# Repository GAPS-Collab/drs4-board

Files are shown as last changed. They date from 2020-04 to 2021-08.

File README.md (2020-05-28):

# Intro
 - altium: contains ECAD project files
 - mfg: contains CAM files (for production ready revisions)
 - peripherals: helpful spreadsheets for address mapping
 - pdf: pdf documents

## Mandatory
Altium does not embed design rules, **they must be imported locally**. When contributing to this project, ensure that you've imported (and are keeping up to date) `altium/rules`

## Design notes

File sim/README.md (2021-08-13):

# SPICE Simulations

Folder containing LTSpice schematics

## Timing calibration LP filter

File: `cheb_7ord.asc`

A high precision (+- 500 ppb) 25 MHz 3V3 LVCMOS (AST3TQ-25.000MHZ-5) TCXO is used for the calibration source. It's make compatible with the DRS4 dynamic range and also shaped using a 7th order Chebyshev LP filter resulting in a roughly 430 mVpp sinewave.

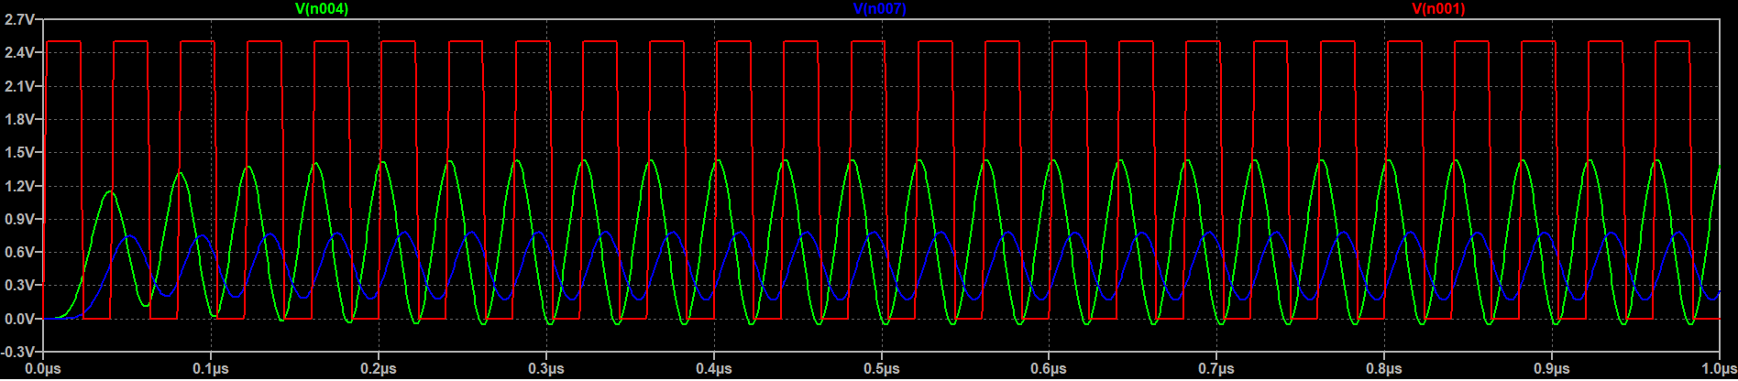
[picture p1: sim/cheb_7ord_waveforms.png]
Example waveform


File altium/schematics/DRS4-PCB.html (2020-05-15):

Altium customize

# Board Information Report

Date: | | 7/10/2019
Time: | | 3:52:31 PM
Elapsed Time: | | 00:00:01
Filename: | | C:\Users\Ismael\Dropbox\GAPS\DRS4_V2\UCLA-DRS4-V2\schematics\DRS4-PCB.PcbDoc
Units: | | mmmils

## Contents

Contents

Board Specification

General

Routing

Routing Information

Layer Information

Layer Information

Drill Pairs

Board Holes

Non-Plated Hole Size

Plated Hole Size

Board Slots

Non-Plated Slot Size

Plated Slot Size

Board Square Holes

Non-Plated Square Hole Size

Plated Square Hole Size

Other

Top Layer Annular Ring Size

Mid Layer Annular Ring Size

Bottom Layer Annular Ring Size

Pad Solder Mask

Pad Paste Mask

Pad Pwr/Gnd Expansion

Pad Relief Conductor Width

Pad Relief Air Gap

Pad Relief Entries

Via Solder Mask

Via Pwr/Gnd Expansion

Track Width

Arc Line Width

Arc Radius

Arc Degrees

Text Height

Text Width

Net Track Width

Net Via Size

## Board Specification

General
Board Size | 313.69mm x 183.14mm
Components on board | 1321

Back to top

## Routing

Routing Information
Routing completion | 80.89%
Connections | 2982
Connections routed | 2412
Connections remaining | 570

Back to top

## Layer Information

Layer | Arcs | Pads | Vias | Tracks | Texts | Fills | Regions | ComponentBodies
Top Layer | 86 | 2519 | 0 | 3016 | 0 | 0 | 257 | 0
Ground Layer 2 | 0 | 0 | 0 | 0 | 0 | 0 | 3 | 0
Signal Layer 3 | 0 | 0 | 0 | 559 | 0 | 0 | 2 | 0
Signal Layer 4 | 1078 | 0 | 0 | 534 | 0 | 0 | 9 | 0
Ground Layer 5 | 0 | 0 | 0 | 0 | 0 | 0 | 0 | 0
Power Layer 6 | 0 | 0 | 0 | 0 | 0 | 0 | 5 | 0
Ground Layer 7 | 0 | 0 | 0 | 0 | 0 | 0 | 0 | 0
Power Layer 8 | 0 | 0 | 0 | 155 | 0 | 0 | 7 | 0
Ground Layer 10 | 0 | 0 | 0 | 0 | 0 | 0 | 0 | 0
Power Layer 9 | 0 | 0 | 0 | 394 | 0 | 0 | 22 | 0
Ground Layer 13 | 0 | 0 | 0 | 0 | 0 | 0 | 0 | 0
Bottom Layer | 0 | 1359 | 0 | 1146 | 0 | 0 | 341 | 0
Mechanical 1 | 0 | 0 | 0 | 0 | 20 | 0 | 0 | 99
Mechanical 4 | 2 | 0 | 0 | 8 | 0 | 0 | 0 | 0
Mechanical 10 | 0 | 0 | 0 | 244 | 61 | 0 | 0 | 0
Mechanical 11 | 0 | 0 | 0 | 4 | 1 | 0 | 0 | 0
Mechanical 12 | 0 | 0 | 0 | 244 | 0 | 0 | 0 | 0
Mechanical 13 | 21 | 0 | 0 | 5786 | 34 | 0 | 0 | 1892
Mechanical 15 | 0 | 0 | 0 | 7624 | 0 | 0 | 32 | 0
Mechanical 16 | 0 | 0 | 0 | 4 | 0 | 0 | 0 | 0
Multi-Layer | 0 | 186 | 3075 | 0 | 0 | 0 | 1 | 0
Top Paste | 0 | 0 | 0 | 0 | 0 | 0 | 94 | 0
Top Overlay | 93 | 0 | 0 | 736 | 1581 | 0 | 0 | 0
Top Solder | 0 | 0 | 0 | 0 | 0 | 0 | 54 | 0
Bottom Solder | 0 | 0 | 0 | 0 | 0 | 0 | 0 | 0
Bottom Overlay | 72 | 0 | 0 | 571 | 1122 | 0 | 0 | 0
Bottom Paste | 0 | 0 | 0 | 0 | 0 | 0 | 4 | 0
Drill Guide | 0 | 0 | 0 | 0 | 0 | 0 | 0 | 0
Keep-Out Layer | 0 | 0 | 0 | 0 | 0 | 0 | 0 | 0
Drill Drawing | 0 | 0 | 0 | 0 | 0 | 0 | 0 | 0
Total | 1352 | 4064 | 3075 | 21025 | 2819 | 0 | 831 | 1991

Back to top

Drill Pairs | Vias
Top Layer - Bottom Layer | 3075
Total | 3075

Back to top

## Board Holes

Non-Plated Hole Size | Pads | Vias
3.2mm | 2 | 0
Total | 2 | 0

Back to top

Plated Hole Size | Pads | Vias
0mm | 3812 | 0
0.2mm | 0 | 478
0.254mm | 0 | 2561
0.4mm | 5 | 36
0.5mm | 2 | 0
0.508mm | 36 | 0
0.762mm | 61 | 0
0.8mm | 13 | 0
0.89mm | 20 | 0
0.9mm | 3 | 0
1mm | 16 | 0
1.03mm | 4 | 0
1.0922mm | 1 | 0
1.57mm | 4 | 0
1.6002mm | 1 | 0
1.8mm | 8 | 0
4.1656mm | 4 | 0
Total | 3990 | 3075

Back to top

## Board Slots

Non-Plated Slot Size / Length | Pads
133.858mil / 133.858mil | 2
Total | 2

Back to top

Plated Slot Size / Length | Pads
27.559mil / 74.803mil | 2
42.52mil / 42.52mil | 2
Total | 4

Back to top

## Board Square Holes

Non-Plated Square Hole Size | Pads
Total | 0

Back to top

Plated Square Hole Size | Pads
Total | 0

Back to top

## Other

Top Layer Annular Ring Size | Count
-0.15mm | 2
0mm | 4
0.246mm | 2560
0.25mm | 28
0.3mm | 450
0.3mm | 36
0.4mm | 5
0.5mm | 6
0.5mm | 2
0.508mm | 46
0.51mm | 12
0.724mm | 13
0.746mm | 1
0.762mm | 61
0.785mm | 2
0.8mm | 6
0.83mm | 2
0.994mm | 8
1mm | 3
1mm | 10
3.8344mm | 4
Total | 3261

Back to top

Mid Layer Annular Ring Size | Count
-0.15mm | 2
0mm | 4
0.246mm | 2560
0.25mm | 28
0.3mm | 450
0.3mm | 36
0.4mm | 5
0.5mm | 6
0.5mm | 2
0.508mm | 46
0.51mm | 12
0.724mm | 13
0.746mm | 1
0.762mm | 61
0.785mm | 2
0.8mm | 6
0.83mm | 2
0.994mm | 8
1mm | 3
1mm | 10
3.8344mm | 4
Total | 3261

Back to top

Bottom Layer Annular Ring Size | Count
-0.15mm | 2
0mm | 4
0.246mm | 2560
0.25mm | 28
0.3mm | 450
0.3mm | 36
0.4mm | 5
0.5mm | 6
0.5mm | 2
0.508mm | 46
0.51mm | 12
0.724mm | 13
0.746mm | 1
0.762mm | 61
0.785mm | 2
0.8mm | 6
0.83mm | 2
0.994mm | 8
1mm | 3
1mm | 10
3.8344mm | 4
Total | 3261

Back to top

Pad Solder Mask | Count
-0.8128mm | 9
0mm | 710
0.1016mm | 3345
Total | 4064

Back to top

Pad Paste Mask | Count
-1.6129mm | 1
-1.2873mm | 1
-1.1873mm | 9
-0.8128mm | 9
0mm | 3978
0.1mm | 66
Total | 4064

Back to top

Pad Pwr/Gnd Expansion | Count
0.127mm | 4064
Total | 4064

Back to top

Pad Relief Conductor Width | Count
0.254mm | 4064
Total | 4064

Back to top

Pad Relief Air Gap | Count
0.254mm | 4064
Total | 4064

Back to top

Pad Relief Entries | Count
4 | 4064
Total | 4064

Back to top

Via Solder Mask | Count
0.1016mm | 3075
Total | 3075

Back to top

Via Pwr/Gnd Expansion | Count
0.127mm | 3075
Total | 3075

Back to top

Track Width | Count
0.0254mm | 1262
0.05mm | 5128
0.1mm | 6248
0.127mm | 1012
0.15mm | 228
0.1524mm | 793
0.1981mm | 23
0.2mm | 4796
0.25mm | 596
0.254mm | 422
0.3mm | 237
0.4mm | 251
0.45mm | 29
Total | 21025

Back to top

Arc Line Width | Count
0mm | 1
0.1mm | 40
0.127mm | 764
0.16mm | 1
0.2mm | 410
0.25mm | 102
0.254mm | 25
0.4mm | 3
0.508mm | 1
0.6mm | 5
Total | 1352

Back to top

Arc Radius | Count
0.05mm | 22
0.07mm | 1
0.1228mm | 1
0.125mm | 102
0.127mm | 40
0.1635mm | 4
0.1635mm | 10
0.2mm | 5
0.254mm | 375
0.3mm | 5
0.3635mm | 36
0.3635mm | 158
0.5mm | 18
0.508mm | 373
0.6905mm | 36
0.6905mm | 6
0.6905mm | 152
1.2681mm | 2
3.6418mm | 2
8.5548mm | 2
24.6781mm | 2
Total | 1352

Back to top

Arc Degrees | Count
7 | 4
19 | 2
32 | 2
90 | 34
166 | 30
180 | 1100
332 | 8
355 | 1
360 | 171
Total | 1352

Back to top

Text Height | Count
0.2mm | 52
0.3mm | 6
0.4mm | 3
0.6mm | 1318
0.7mm | 8
0.8mm | 6
1mm | 62
1.27mm | 43
1.524mm | 1321
Total | 2819

Back to top

Text Width | Count
0.05mm | 55
0.06mm | 5
0.065mm | 1
0.0762mm | 43
0.1mm | 75
0.12mm | 1318
0.2mm | 1
0.254mm | 1321
Total | 2819

Back to top

Net Track Width | Count
0.127mm | 956
0.254mm | 84
Total | 1040

Back to top

Net Via Size | Count
1.25mm | 1040
Total | 1040

Back to top

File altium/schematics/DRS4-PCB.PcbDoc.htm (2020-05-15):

Reporting Options

# File in Newer Format

Date | : | 4/23/2020
Time | : | 12:48:40 PM
Filename | : | C:\Users\Ismae\Dropbox\GAPS\DRS\DRS_V2.1\UCLA-DRS4-V2\schematics\DRS4-PCB.PcbDoc

Version | Warning
Release 20.0 | CAUTION - Support of propagation delay for primitives
Release 19.0 | CAUTION - File contains precalculated impedance profiles
Release 20.0 | CAUTION - Support for PCB system parameters, used to contain additional data extracted from components

This file was generated by a later version of the software

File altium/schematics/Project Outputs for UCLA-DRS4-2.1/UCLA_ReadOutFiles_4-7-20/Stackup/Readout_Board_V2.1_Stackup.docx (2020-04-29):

Layer 3:

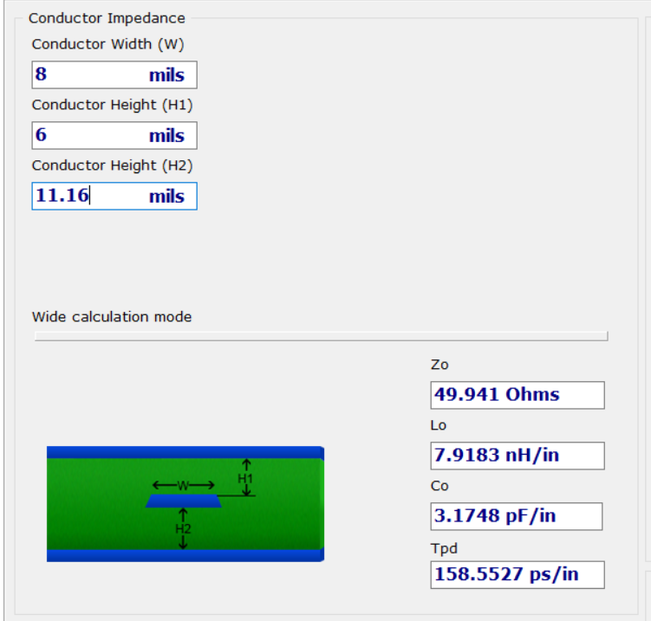
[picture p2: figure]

Layer 4:

Single Ended – 50 Ohm

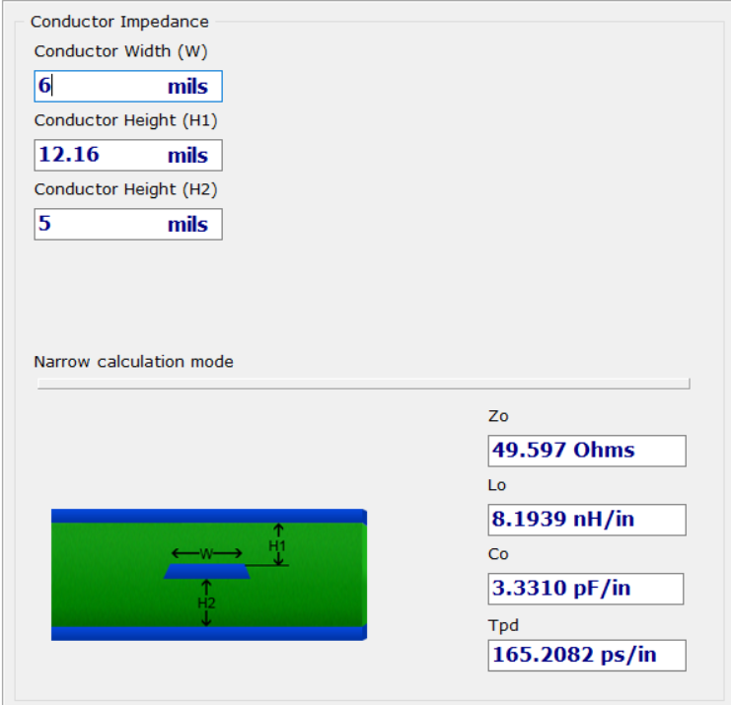
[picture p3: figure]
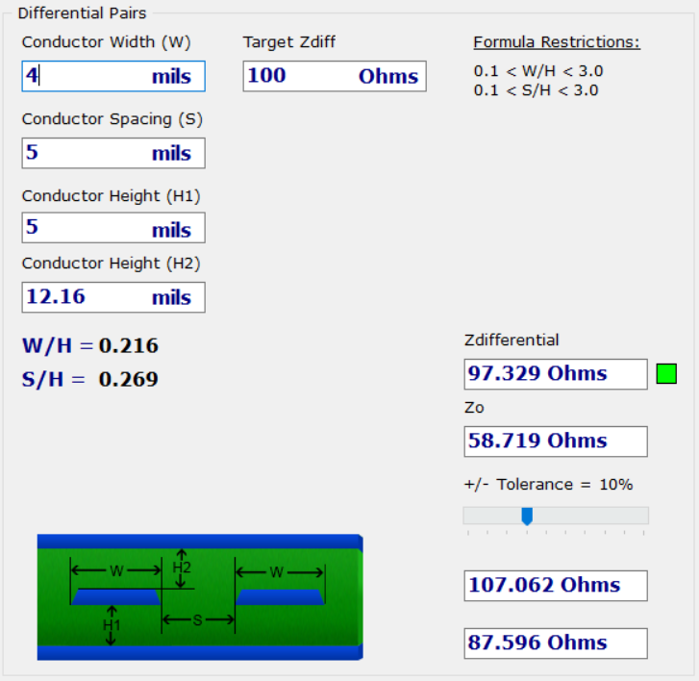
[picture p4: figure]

Layer 10

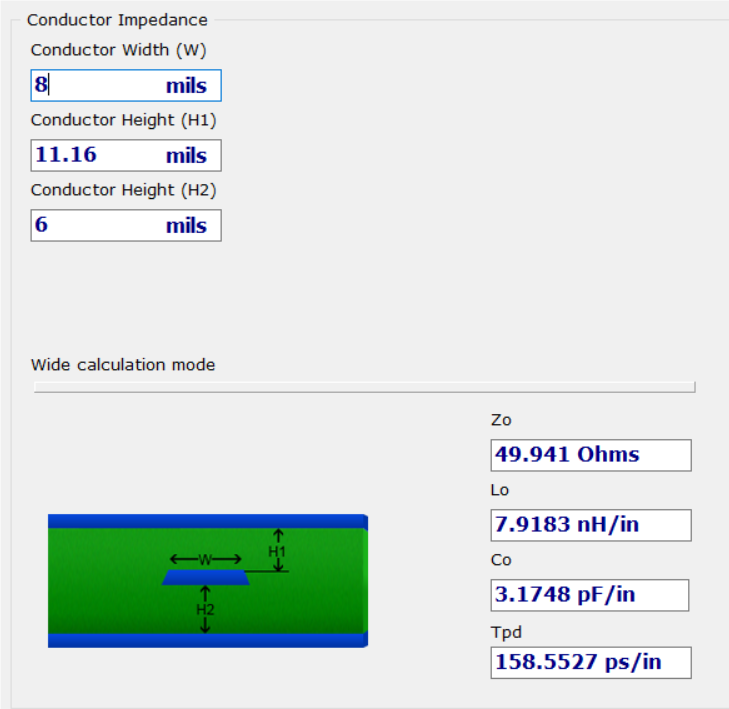
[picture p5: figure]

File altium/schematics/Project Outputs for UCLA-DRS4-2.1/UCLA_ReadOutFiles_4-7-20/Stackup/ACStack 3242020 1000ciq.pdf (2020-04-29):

StackName: ACStack 3242020 1000ciq | Version: | Revision: | Modification: | Date of Revision: | Editor | Page 1/3
Date: 3/24/2020 | Associated Documents: 17823cio

Author: MS
Department: CI Eng
Site: Aurora

Copyright ©

www.polarinstruments.com

Taiyo | PSR-4000BN (semi gloss) | soldermask | 4.500 | 0.800 | 0.800
1 | Isola | 1/2 oz copper foil | foil | 0.600 | 1.600 | 1, 2
Isola | FR408HR 106(75) pre-preg | pre-preg | 2.300 | 3.230 | 2.060
Isola | FR408HR 106(75) pre-preg | pre-preg | 2.300 | 3.230 | 2.060
2 | | | | 1.200 | 1.200
Isola | FR408HR .006 (1080/3313-56) 1/1 core* | core | 6.000 | 3.640 | 6.000
3 | | | | 1.200 | 1.200 | 3
Isola | FR408HR 1080(65) pre-preg | pre-preg | 3.200 | 3.440 | 2.480
Isola | FR408HR 1080(65) pre-preg | pre-preg | 3.200 | 3.440 | 2.480
4 | | | | 1.200 | 1.200 | 4, 5
Isola | FR408HR .005 (1/2116-54) 1/1 core* | core | 5.000 | 3.690 | 5.000
5 | | | | 1.200 | 1.200
Isola | FR408HR 106(75) pre-preg | pre-preg | 2.300 | 3.230 | 1.820
Isola | FR408HR 106(75) pre-preg | pre-preg | 2.300 | 3.230 | 1.820
6 | | | | 1.200 | 1.200
Isola | FR408HR .004 (106/1080-59) 1/1 core* | core | 4.000 | 3.570 | 4.000
7 | | | | 1.200 | 1.200
Isola | FR408HR 106(75) pre-preg | pre-preg | 2.300 | 3.230 | 1.820
Isola | FR408HR 106(75) pre-preg | pre-preg | 2.300 | 3.230 | 1.820
8 | | | | 1.200 | 1.200
Isola | FR408HR .005 (1/2116-54) 1/1 core* | core | 5.000 | 3.690 | 5.000
9 | | | | 1.200 | 1.200 | 6
Isola | FR408HR 1080(65) pre-preg | pre-preg | 3.200 | 3.440 | 2.480
Isola | FR408HR 1080(65) pre-preg | pre-preg | 3.200 | 3.440 | 2.480
10 | | | | 1.200 | 1.200 | 7
Isola | FR408HR .006 (1080/3313-56) 1/1 core* | core | 6.000 | 3.640 | 6.000
11 | | | | 1.200 | 1.200
Isola | FR408HR 106(75) pre-preg | pre-preg | 2.300 | 3.230 | 2.060
Isola | FR408HR 106(75) pre-preg | pre-preg | 2.300 | 3.230 | 2.060
12 | Isola | 1/2 oz copper foil | foil | 0.600 | 1.600 | 8, 9
Taiyo | PSR-4000BN (semi gloss) | soldermask | 4.500 | 0.800 | 0.800

66.700 +6.670 / -6.670

1 | Coated Microstrip 1B | 1 | 2 | 0 | 7.870 | 7.370 | 0.000 | 0.000 | 50.000 | 49.870 | 10.000
2 | Edge Coupled Coated Microstrip 1B | 1 | 2 | 0 | 5.000 | 4.500 | 5.000 | 0.000 | 100.000 | 98.240 | 10.000
3 | Offset Stripline 1B2A | 3 | 2 | 5 | 9.800 | 9.300 | 0.000 | 0.000 | 50.000 | 42.620 | 10.000

StackName: ACStack 3242020 1000ciq | Version: | Revision: | Modification: | Date of Revision: | Editor | Page 2/3
Date: 3/24/2020 | Associated Documents: 17823cio

Author: MS

4 | Offset Stripline 1B2A | 4 | 2 | 5 | 9.800 | 9.800 | 0.000 | 0.000 | 50.000 | 39.280 | 10.000
5 | Edge Coupled Offset Stripline 1B2A | 4 | 2 | 5 | 5.000 | 5.000 | 5.000 | 0.000 | 100.000 | 88.550 | 10.000
6 | Offset Stripline 1B2A | 9 | 8 | 11 | 9.840 | 9.840 | 0.000 | 0.000 | 50.000 | 39.190 | 10.000
7 | Offset Stripline 1B2A | 10 | 8 | 11 | 9.840 | 9.840 | 0.000 | 0.000 | 50.000 | 42.040 | 10.000
8 | Coated Microstrip 1B | 12 | 11 | 0 | 7.870 | 7.370 | 0.000 | 0.000 | 50.000 | 49.870 | 10.000
9 | Edge Coupled Coated Microstrip 1B | 12 | 11 | 0 | 7.870 | 7.370 | 5.000 | 0.000 | 80.000 | 81.870 | 10.000
1 | 12 | 1 | Mechanical PTH | 0 | 20.000

Here's the requested stack up.

Dielectric Impedance Design Notes:

1) Impedance stack up is based on our current data review.
2) Production stack up may require adjustment and is subject to final review.
3) Your Design Line widths and spacing require adjustment to match dielectric impedance calculations.
Please review the provided Polar Speed Stack drawing and review the calculated impedance as compared to targeted results. Line width adjustments will be greater than 1 mil.
Taiyo | PSR-4000BN (semi gloss) | PSR-4000BN (semi gloss) | soldermask | 2
Isola | 1/2 oz copper foil | 1/2 oz copper foil | foil | 2

StackName: ACStack 3242020 1000ciq | Version: | Revision: | Modification: | Date of Revision: | Editor | Page 3/3
Date: 3/24/2020 | Associated Documents: 17823cio

Author: MS

Isola | FR408HR 106(75) pre-preg | FR408HR 106(75) pre-preg | pre-preg | 8
Isola | FR408HR .006 (1080/3313-56) 1/1 core* | FR408HR .006 (1080/3313-56) 1/1 core* | core | 2
Isola | FR408HR 1080(65) pre-preg | FR408HR 1080(65) pre-preg | pre-preg | 4
Isola | FR408HR .005 (1/2116-54) 1/1 core* | FR408HR .005 (1/2116-54) 1/1 core* | core | 2
Isola | FR408HR .004 (106/1080-59) 1/1 core* | FR408HR .004 (106/1080-59) 1/1 core* | core | 1

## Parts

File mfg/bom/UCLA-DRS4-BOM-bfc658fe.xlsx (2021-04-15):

Line # | Designator | Quantity | Description | Manufacturer 1 | Manufacturer Part Number 1 | Manufacturer Lifecycle 1 | Supplier 1 | Supplier Part Number 1 | Supplier Unit Price 1 | Supplier Subtotal 1
1 | C1, C2, C3, C4, C5, C6, C29, C30, C52, C53, C145, C146, C147, C148, C149 | 15 | Tantalum Capacitors - Polymer SMD 25V 22uF 1311 20% ESR=100mOhms | KEMET | T521B226M025ATE100 | Unknown | Mouser | 80-T521B226M25ATE100 | 0.813 | 12.2
2 | C7, C9, C10, C11, C12, C14, C15, C16, C17, C18, C19, C21, C23, C24, C25, C27, C28, C31, C32, C33, C35, C36, C38, C42, C43, C44, C45, C47, C49, C50, C51, C54, C56, C65, C76, C244 | 36 | CAP CER 4.7uF 35V X5R 0603 | Murata | ZRB18AR6YA475ME05L | Unknown | Mouser | 81-ZRB18AR6YA475ME5L | 0.265 | 9.54
3 | C8, C13, C22, C26, C34, C37, C39, C46, C48, C57, C61, C62, C94, C95, C242, C251, C253, C258, C262, C327 | 20 | CAP CER 10nF 50V X7R 0603 | KEMET | C0603C103J5RACTU | Volume Production | Mouser | 80-C0603C103J5R | 0.024 | 0.48
4 | C20, C40, C41, C55, C58, C59, C60, C86, C87, C88, C89, C90, C91, C93, C102, C109, C110, C111, C112, C113, C115, C116, C117, C118, C119, C121, C122, C126, C128, C129, C131, C132, C133, C134, C139, C140, C141, C142, C143, C151, C152, C153, C154, C155, C162, C163, C165, C166, C168, C170, C171, C172, C173, C174, C175, C177, C179, C185, C186, C187, C188, C189, C192A, C192B, C192C, C192D, C192E, C192F, C192G, C192H, C194A, C194B, C194C, C194D, C194E, C194F, C194G, C194H, C196A, C196B, C196C, C196D, C196E, C196F, C196G, C196H, C197A, C197B, C197C, C197D, C197E, C197F, C197G, C197H, C198A, C198B, C198C, C198D, C198E, C198F, C198G, C198H, C199A, C199B, C199C, C199D, C199E, C199F, C199G, C199H, C202A, C202B, C202C, C202D, C202E, C202F, C202G, C202H, C205A, C205B, C205C, C205D, C205E, C205F, C205G, C205H, C212A, C212B, C212C, C212D, C212E, C212F, C212G, C212H, C213, C215, C217, C218, C219, C220, C223, C226, C233, C238, C239, C240, C241, C245, C247, C248, C249, C250, C252, C254, C255, C256, C257, C259, C261, C264, C265, C266, C268, C269, C270, C276, C315, C316, C317, C318, C322, C324, C325, C328, C329, C330 | 176 | CAP CER 100nF 25V X7R 0402 | Taiyo Yuden | TMK105B7104KV-FR | Unknown | Mouser | 963-TMK105B7104KV-FR | 0.034 | 5.98
5 | C63, C64, C66, C70, C74, C75, C77, C81, C114, C127, C144, C150, C176, C184, C200A, C200B, C200C, C200D, C200E, C200F, C200G, C200H, C201A, C201B, C201C, C201D, C201E, C201F, C201G, C201H, C203A, C203B, C203C, C203D, C203E, C203F, C203G, C203H, C204A, C204B, C204C, C204D, C204E, C204F, C204G, C204H, C221, C222, C224, C225, C243, C275, C321, C323, C326, C342 | 56 | CAP CER 10uF 25V X7R 0805 | Murata | GRM21BC71E106ME11L | Volume Production | Mouser | 81-GRM21BC71E106ME1L
6 | C67, C68, C69, C71, C72, C73, C78, C79, C80, C82, C83, C84, C96, C97, C98, C99, C100, C101, C103, C104, C105, C106, C107, C108, C124, C267, C272, C273, C274, C319, C333, C334, C338 | 33 | CAP CER 1uF 25V X7R 0603 | Murata | GCJ188R71E105KA01J | Unknown | Mouser | 81-GCJ188R71E105KA1J | 0.225 | 7.43
7 | C85, C130, C159, C160, C161 | 5 | Multilayer Ceramic Capacitors MLCC - SMD/SMT 0402 20pF 50Volts C0G 2% | Murata | GJM1555C1H200GB01D | Volume Production | Mouser | 81-GJM1555C1H200GB01 | 0.087 | 0.87
8 | C92 | 1 | MLCC - SMD/SMT 0402 50VDC 12pF 1% AEC-Q200 | Murata | GCQ1555C1H120FB01D | Unknown | Mouser | 81-GCQ1555C1H120FB1D | 0.54 | 0.54
9 | C120 | 1 | CAP CER 5600PF 50V X7R 0402 C0402C562K5RACTU | KEMET | C0402C562K5RACTU | Volume Production
10 | C123, C277, C278 | 3 | CAP CER 22uF 25V X5R 0805 | Murata | GRT21BR61E226ME13L | Volume Production | Mouser | 81-GRT21BR61E226ME3L | 0.58 | 1.74
11 | C125, C271 | 2 | CAP 4.7nF 10V ±10% 0603 (1608 Metric) Thickness 1mm SMD | KEMET | C0603C472K8RACTU | Volume Production | Mouser | 80-C0603C472K8R | 0.1 | 0.2
12 | C135, C156 | 2 | CAP CER 100uF 25V X5R 1206 | Murata | GRM31CR61A107ME05L | Unknown | Mouser | 81-GRM31CR61A107ME5L | 0.78 | 1.56
13 | C136, C137, C138, C157, C158 | 5 | CAP CER 100pF 50V X7R 0603 | KEMET | C0603C101J5RAC7867 | Unknown | Mouser | 80-C0603C101J5R | 0.116 | 1.16
14 | C164, C167 | 2 | Tantalum Capacitor, 10 uF, +/- 20%, 10 V, -55 to 125 degC, 2-Pin SMD (M), RoHS, Tape and Reel | Vishay Sprague | TR8M106M010C2000 | Volume Production | Mouser | 74-TR8M106M010C2000 | 1.99 | 3.98
15 | C178, C180, C181, C182, C183, C190, C191 | 7 | CAP CER 1nF 50V X7R 0603 | KEMET | C0603C102J5RACAUTO | Volume Production | Mouser | 80-C0603C102J5RAUTO | 0.042 | 0.42
16 | C193A, C193B, C193C, C193D, C193E, C193F, C193G, C193H, C195A, C195B, C195C, C195D, C195E, C195F, C195G, C195H, C214, C216 | 18 | CAP CER 470nF 25V X7R 0603 | Wurth Electronics | 885012206075 | Volume Production | Mouser | 710-885012206075 | 0.091 | 1.64
17 | C206A, C206B, C206C, C206D, C206E, C206F, C206G, C206H, C207A, C207B, C207C, C207D, C207E, C207F, C207G, C207H, C208A, C208B, C208C, C208D, C208E, C208F, C208G, C208H, C209A, C209B, C209C, C209D, C209E, C209F, C209G, C209H, C210A, C210B, C210C, C210D, C210E, C210F, C210G, C210H, C211A, C211B, C211C, C211D, C211E, C211F, C211G, C211H, C227, C228, C229, C230, C231, C232 | 54 | CAP CER 220nF 50V X7R 0402 | TDK | C1005X7R1E224K050BE | Volume Production | Mouser | 810-C1005X7R1E224KBE | 0.09 | 4.86
18 | C234, C235, C279, C282, C283, C286, C287, C290, C291, C294, C295, C298, C299, C302, C303, C306, C307, C310, C311, C314 | 20 | CAP 150pF 50V C0G ±1% 0402 (1000 Metric) Thickness 1mm SMD | TDK | CGA2B2C0G2A151J050BE | Unknown | Mouser | 810-CGA2B2C0G2A151J0 | 0.061 | 1.22
19 | C236, C237, C280, C281, C284, C285, C288, C289, C292, C293, C296, C297, C300, C301, C304, C305, C308, C309, C312, C313 | 20 | CAP 270pF 50V C0G ±1% 0402 | Murata | GCM1555C1H271FA16D | Unknown | Mouser | 81-GCM1555C1H271FA6D | 0.051 | 1.02
20 | C246 | 1 | CAP 2.2uF 16V ±10% 0603 (1608 Metric) Thickness 1mm SMD | KEMET | C0603C225K4PACTU | Volume Production | Mouser | 80-C0603C225K4P | 0.13 | 0.13
21 | C260 | 1 | Tantalun Capacitor, 1 uF, +/- 10%, 16 V, -55 to 125 degC, 2-Pin SMD, RoHS, Tape and Reel | KEMET | T491A105K016AT | Volume Production | Mouser | 80-T491A105K016 | 0.35 | 0.35
22 | C339, C341 | 2 | CAP CER 100nF 50V X7R 0603 | KEMET | C0603C104M5RACAUTO | Volume Production | Mouser | 80-C0603C104M5RAUTO | 0.12 | 0.24
23 | D1, D2, D3, D4 | 4 | Transient Voltage Suppressor, Micro-Packaged Diode for ESD Protection, 2-Pin SOD-923, Pb-Free, Tape and Reel | ON Semiconductor | ESD9B5.0ST5G | Volume Production | Newark | 94T5750 | 0.022 | 0.088
24 | D5, D6, D7, D19, D31, D32 | 6 | Zener Diodes 500mW 4.3V Zener AEC-Q101 Qualified | Diodes | BZT52C4V3-7-F | Volume Production | Mouser | 621-BZT52C4V3-F | 0.21 | 1.26
25 | D8, D9, D10, D11, D12, D14, D15, D17, D18, D21 | 10 | Diodes - General Purpose, Power, Switching SINGLE JUNC. 75V 4.0NS COMP | ON Semiconductor / Fairchild | 1N4148WT | Volume Production | Mouser | 512-1N4148WT | 0.15 | 1.5
26 | D20, D22 | 2 | Standard LEDs - SMD Green 470nm 28mcd 20mA | Vishay Lite-On | LTST-C193KGKT-5A | Volume Production | Mouser | 859-LTSTC193KGKT5A | 0.39 | 0.78
27 | D23, D26, D27, D33, D34, D35, D36, D37, D38, D45, D46, D48 | 12 | Standard LEDs - SMD Red 470nm 28mcd 20mA | Vishay Lite-On | LTST-C193KRKT-5A | Volume Production | Mouser | 859-LTSTC193KRKT5A | 0.21 | 2.52
28 | D24, D49, D50, D54, D55, D56, D57 | 7 | ESD Suppressors / TVS Diodes 5.5V QUAD R-R ESD ULTRA LOW CAP | Nexperia USA | PRTR5V0U4D,125 | Unknown | Mouser | 771-PRTR5V0U4D-T/R | 0.46 | 3.22
29 | D25, D28, D29, D30, D41 | 5 | ESD Suppressors / TVS Diodes 4 Ch 8kV 0.65pF SPA | Littelfuse | SP3003-04ATG | Volume Production | Mouser | 576-SP3003-04ATG | 1.44 | 7.2
30 | D39A, D39B, D39C, D39D, D39E, D39F, D39G, D39H, D40 | 9 | Silicon Switching Diode, SOT363, Reel, Green | Infineon | BAV99S | Not Recommended for New Design | Mouser | 726-BAV99SH6327 | 0.32 | 3.2
31 | D42 | 1 | ESD Suppressors / TVS Diodes SO-8 5V 500W Low Capacitance | Bourns | CDNBS08-SRDA05-4 | Volume Production | Mouser | 652-CDNBS08-SRDA05-4 | 1.82 | 1.82
32 | D43, D44, D59, D60, D61, D62, D63, D64, D65, D66, D67, D68, D69, D70, D71, D72, D73, D74, D75, D76, D77, D78, D79, D80, D81 | 25 | Standard LEDs - SMD Blue 470nm 28mcd 20mA | Vishay Lite-On | LTST-C193TBKT-5A | Volume Production | Mouser | 859-LTSTC193TBKT5A | 0.23 | 5.75
33 | F1, F2, F3, F5 | 4 | Resettable Fuses - PPTC 3A 24V PPTC 2920 SMD | Bel | 0ZCF0300BF2C | Volume Production | Mouser | 530-0ZCF0300BF2C | 0.44 | 1.76
34 | F4 | 1 | 2A hold, 3.5A trip | Bel | 0ZCG0200AF2B | Volume Production | Digi-Key | 507-2074-6-ND | 0.22 | 0.22
35 | FB1, FB2, FB3, FB4, FB5, FB29 | 6 | Chip Bead Inductor for Power Lines, 680 Ohm, 4 A, -40 to 125 degC, 2-Pin 4.5 x 3.2 x 3.5 mm SMD, RoHS, Taping | Taiyo Yuden | FBMH4532HM681-T | Volume Production | Digi-Key | 587-1761-6-ND | 0.55 | 3.3
36 | FB6, FB7 | 2 | Feb SMD 30 OHM 25% 3/4W 0402 | Murata | BLM15AX300SZ1D | Unknown | Mouser | 81-BLM15AX300SZ1D | 0.12 | 0.24
37 | FB8, FB9, FB10A, FB10B, FB10C, FB10D, FB10E, FB10F, FB10G, FB10H, FB11A, FB11B, FB11C, FB11D, FB11E, FB11F, FB11G, FB11H, FB12A, FB12B, FB12C, FB12D, FB12E, FB12F, FB12G, FB12H, FB13, FB14, FB15, FB17, FB18, FB20, FB21, FB22, FB24, FB25, FB26, FB27, FB28 | 39 | FB SMD 100 OHM 25% 1.2A 0402 | Wurth Electronics | 742792731 | Volume Production | Mouser | 710-742792731
38 | FB16, FB23 | 2 | FB SMD 1000 OHM 25% 3/4W 0402 | Murata | BLM15AX102SZ1D | Unknown | Mouser | 81-BLM15AX102SZ1D
39 | J1 | 1 | Connector | HARTING Technology | 09452819001 | Unknown | Digi-Key | 1195-09452819001CT-ND | 4.28 | 4.28
40 | J2 | 1 | Headers & Wire Housings RA HDR W/O PEGS 8P | TE Connectivity | 1586041-8 | Volume Production | Mouser | 571-15860418 | 0.92 | 0.92
41 | J3 | 1 | Headers & Wire Housings UNSHRD VERT SNGL 3 | TE Connectivity | 87224-3 | Volume Production | Mouser | 571-872243 | 1.06 | 1.06
42 | J4 | 1 | DIMM Connectors DDR2 SODIMM 200P STANDARD HOUSING | AMP - TE CONNECTIVITY | 1473005-4 | Unknown | Mouser | 571-1473005-4 | 4.38 | 4.38
43 | J5 | 1 | Headers & Wire Housings 14P SMD PB FREE SHRD | Molex | 87832-1420 | Volume Production | Mouser | 538-87832-1420 | 1.83 | 1.83
44 | J6, J7, J8, J10, J11 | 5 | Headers & Wire Housings 2P SINGLE ROW 5A | AMP - TE CONNECTIVITY | 826936-2 | Unknown | Mouser | 571-826936-2 | 0.27 | 1.35
45 | J9A, J9B, J9C, J9D, J9E, J9F, J9G, J9H | 8 | CONN SMA JACK 50 OHM EDGE MNT | Amphenol Connex | 132289 | Volume Production | Mouser | 523-132289 | 7.41 | 59.28
46 | J12 | 1 | USB Connectors WR-COM USB Micro SMT Type B Horiztl | Wurth Electronics | 629105150521 | Volume Production | Mouser | 710-629105150521 | 2.15 | 2.15
47 | J13 | 1 | CONN MICRO SD CARD HINGED TYPE | Molex | 47219-2001 | Volume Production | Mouser | 538-47219-2001 | 1.44 | 1.44
48 | J14 | 1 | Connector | Molex | 10-89-7442 | Volume Production | Mouser | 538-10-89-7442 | 2.78 | 2.78
49 | J15 | 1 | Headers & Wire Housings 2 WAY SIL VERT PC TAIL P/HDR | Harwin | M50-3530242 | Unknown | Mouser | 855-M50-3530242 | 0.12 | 0.12
50 | J16 | 1 | Connector | Wurth Electronics | 61300611121 | Volume Production | Mouser | 710-61300611121 | 0.34 | 0.34
51 | J17 | 1 | Connector | Wurth Electronics | 61300711121 | Volume Production | Digi-Key | 732-5320-ND | 0.37 | 0.37
52 | L1, L9 | 2 | IND 10µH Shielded Multilayer Inductor 250mA 1.365 Ohm Max 0603 (1608 Metric) | TDK | MLZ1608M100WT000 | Volume Production | Digi-Key | 445-6389-1-ND | 0.16 | 0.32
53 | L2A, L2B, L2C, L2D, L2E, L2F, L2G, L2H, L3A, L3B, L3C, L3D, L3E, L3F, L3G, L3H, L4, L5 | 18 | Fixed Inductors .22 UH 5% | TDK | MLG1005SR22JT000 | Volume Production | Mouser | 810-MLG1005SR22JT000 | 0.041 | 0.738
54 | L6, L8, L10, L12, L13, L15, L16, L18, L19, L21, L22, L24, L25, L27, L28, L30, L31, L33, L34, L36 | 20 | IND 470nH Shielded Multilayer Inductor 50mA 420 mOhm Max 0402 (1005 Metric) | TDK | MLF1005GR47JT000 | Volume Production | Mouser | 810-MLF1005GR47JT000 | 0.203 | 4.06
55 | L7, L11, L14, L17, L20, L23, L26, L29, L32, L35 | 10 | IND 510nH Shielded Multilayer Inductor 70mA 10.2 Ohm Max 0402 (1005 Metric) | TDK | MHQ1005PR51GT000 | Unknown | Mouser | 810-MHQ1005PR51GT000 | 0.157 | 1.57
56 | OP1A, OP1B, OP1C, OP1D, OP1E, OP1F, OP1G, OP1H, OP2 | 9 | Differential Amplifier 1 Circuit Differential 16-QFN (3x3) | Texas Instruments | THS4509RGTT | Volume Production | Mouser | 595-THS4509RGTT | 8.94 | 80.46
57 | OP3 | 1 | IC OPAMP GP 4 CIRCUIT 14SOIC | Analog Devices | AD8608ARZ-REEL | Volume Production
58 | Q1, Q2, Q3, Q4 | 4 | MOSFET Pch -100V Vds -25A 0.05Rds(on) 60Qg | Rohm | RSJ250P10FRATL | Unknown | Mouser | 755-RSJ250P10FRATL | 1.55 | 6.2
59 | Q5, Q6, Q11, Q38 | 4 | MOSFET Small Signal Dual N-CH 20V .3A .15W | Rohm | EM6K6T2R | Volume Production | Digi-Key | EM6K6T2RCT-ND | 0.45 | 1.8
60 | Q7, Q8, Q9, Q15, Q16, Q17, Q18, Q19, Q20, Q22, Q23, Q25 | 12 | Bipolar Transistors - BJT Transistor for Low Freq. Amplification | Toshiba | TMBT3906,LM | Volume Production | Mouser | 757-TMBT3906LM | 0.154 | 1.85
61 | Q10, Q12, Q13, Q14 | 4 | P-Channel 30V 4A (Ta) 1.4W (Ta) Surface Mount SOT-23-3L | Alpha & Omega Semiconductor | AO3401A | Volume Production | Digi-key | 785-1001-1-ND
62 | Q21, Q26, Q27, Q28, Q29, Q30, Q31, Q32, Q33, Q34, Q35 | 11 | Bipolar Transistors - BJT NPN+NPN 30VCEO 1A SOT-363T | Rohm | US6X8TR | Unknown | Mouser | 755-US6X8TR | 0.454 | 4.99
63 | Q36, Q37 | 2 | Bipolar Transistors - BJT Bipolar Transistor SOT-563 SC-107C EMT6 | Rohm | EMT52T2R | Volume Production | Mouser | 755-EMT52T2R | 0.32 | 0.64
64 | Q39 | 1 | TRANS MOSFET N-CH 30V 3.1A 0402 | Texas Instruments | CSD17381F4 | Volume Production | Mouser | 595-CSD17381F4 | 0.42 | 0.42
65 | R1, R3, R5, R14 | 4 | RES 0.039 OHM 1% 1W 2412 | Ohmite | LVK24R039FER | Not Recommended for New Design | Mouser | 588-LVK24R039FER | 1.69 | 6.76
66 | R2, R4, R6, R22, R25, R26, R28, R29, R124, R125 | 10 | 47K 0.1W 5% 0603 (1608 Metric) SMD | Yageo | RC0603JR-0747KL | Volume Production | Mouser | 603-RC0603JR-0747KL | 0.015 | 0.15
67 | R7, R18, R120 | 3 | 27K 0.1W 5% 0603 (1608 Metric) SMD | Vishay Dale | CRCW060327K0JNTA | Volume Production | Arrow Electronics | CRCW060327K0JNTA | 0.0037 | 0.0111
68 | R8, R9 | 2 | 24K 0.1W 5% 0603 (1608 Metric) SMD | Bourns | CR0603-JW-243ELF | Volume Production | Mouser | 652-CR0603JW-243ELF | 0.014 | 0.14
69 | R10, R34, R51, R53, R63, R65, R95, R107, R121, R122, R123, R129, R141, R167, R168, R204, R205, R215, R216, R222, R301, R302, R303, R304, R305, R306, R307, R308, R317, R318, R319, R320, R321, R322, R323, R324, R329, R330, R331, R332, R333, R334, R335 | 43 | 10K 0.1W 5% 0603 (1608 Metric) SMD | Yageo | RC0603JR-0710KL | Volume Production | Mouser | 603-RC0603JR-0710KL | 0.015 | 0.645
70 | R11 | 1 | Thick Film Resistors - SMD 2.49K ohm 1% 50V General Purpose | Yageo | RC0402FR-132K49L | Volume Production | Mouser | 603-RC0402FR-132K49L | 0.1 | 0.1
71 | R12 | 1 | 22K 0.1W 5% 0603 (1608 Metric) SMD | Yageo | RC0603JR-0722KL | Volume Production | Mouser | 603-RC0603JR-0722KL | 0.1 | 0.1
72 | R13, R16, R19, R20, R37, R38, R39, R40 | 8 | 20K 0.1W 1% 0603 (1608 Metric) SMD | Bourns | CR0603-FX-2002ELF | Volume Production | Mouser | 652-CR0603FX-2002ELF | 0.008 | 0.08
73 | R17 | 1 | 15K 0.1W 5% 0603 (1608 Metric) SMD | Panasonic | ERJ-3GEYJ153V | Volume Production | Digi-Key | P15KGCT-ND | 0.1 | 0.1
74 | R21 | 1 | 33K 0.1W 5% 0603 (1608 Metric) SMD | Bourns | CR0603-JW-333ELF | Volume Production | Mouser | 652-CR0603JW-333ELF | 0.1 | 0.1
75 | R23, R27, R35, R54, R55, R61, R62, R100, R108, R130, R147, R169, R170, R202, R203, R218, R219, R223, R293, R294, R295, R296, R297, R298, R299, R300, R309, R310, R311, R312, R313, R314, R315, R316, R325, R326, R327, R328, R336, R337, R338 | 41 | 680R 0.1W 5% 0603 (1608 Metric) SMD | Yageo | RC0603JR-07680RL | Volume Production | Mouser | 603-RC0603JR-07680RL | 0.017 | 0.697
76 | R24, R31, R200 | 3 | 1K 0.1W 5% 0603 (1608 Metric) SMD | Bourns | CR0603-JW-102ELF | Volume Production | Mouser | 652-CR0603-JW-102ELF | 0.008 | 0.08
77 | R30, R33, R64, R66, R67, R68, R70, R71, R72, R73, R74, R75, R76, R77, R78, R79, R80, R81, R82, R83, R84, R85, R86, R87, R88, R90, R92, R94, R103, R105, R144, R145, R146, R148, R149, R150, R151, R152, R153, R154, R157, R158, R159, R160, R161, R162, R165, R166, R198, R199, R201, R206, R207, R208, R212, R213, R214, R248, R249 | 59 | 0R 0.062W 1% 0402 (1005 Metric) SMD | Vishay | CRCW04020000Z0EDC | Volume Production | Mouser | 71-CRCW04020000Z0EDC | 0.006 | 0.6
78 | R32, R48, R49, R91, R104, R119, R139, R163, R164, R209, R210, R221 | 12 | 100K 0.1W 5% 0603 (1608 Metric) SMD | Yageo | RC0603JR-07100KL | Volume Production | Mouser | 603-RC0603JR-07100KL | 0.015 | 0.18
79 | R36 | 1 | 20R 62.5mW 1% 0402 (1005 Metric) SMD | Rohm | SFR01MZPF20R0 | Unknown | Mouser | 755-SFR01MZPF20R0 | 0.11 | 0.11
80 | R41, R43, R44, R56, R57, R93, R98, R109, R110, R111, R112, R113, R114, R115, R116, R117 | 16 | 100R 0.063W 5% 0402 (1005 Metric) SMD | Bourns | CR0402-JW-101GLF | Volume Production | Mouser | 652-CR0402JW-101GLF | 0.01 | 0.16
81 | R42, R50, R52, R140, R143, R179A, R179B, R179C, R179D, R179E, R179F, R179G, R179H, R180A, R180B, R180C, R180D, R180E, R180F, R180G, R180H, R191, R192 | 23 | 22R 0.063W 1% 0402 (1005 Metric) SMD | Bourns | CR0402-FX-22R0GLF | Volume Production | Mouser | 652-CR0402FX-22R0GLF | 0.012 | 0.276
82 | R45, R106, R172A, R172B, R172C, R172D, R172E, R172F, R172G, R172H, R183 | 11 | 49R9 0.063W 1% 0402 (1005 Metric) SMD | Bourns | CR0402-FX-49R9GLF | Volume Production | Mouser | 652-CR0402FX-49R9GLF | 0.005 | 0.055
83 | R46, R47, R196, R197 | 4 | 0603 Do not place resistor
84 | R58 | 1 | 8K 0.1W 1% 0603 (1608 Metric) SMD | Yageo | RT0603BRE078KL | Not Recommended for New Design | Mouser | 603-RT0603BRE078KL
85 | R59 | 1 |  | Panasonic | ERJ-3EKF4530V | Volume Production | Digi-Key | P453HCT-ND | 0.1 | 0.1
86 | R60 | 1 |  | Panasonic | ERJ-3EKF5490V | Volume Production | Digi-Key | P549HDKR-ND | 0.1 | 0.1
87 | R69, R194, R195, R263, R264, R265, R266, R269, R270, R271, R272, R275, R276, R277, R278, R281, R282, R283, R284, R286, R287 | 21 | 300R 0.063W 1% 0402 (1005 Metric) SMD | Bourns | CR0402-FX-3000GLF | Volume Production | Mouser | 652-CR0402FX-3000GLF | 0.012 | 0.252
88 | R89, R118, R127, R128 | 4 | Current Sense Resistors - SMD .1 OHM.25% 3/4W | Ohmite | LVK20R100CER | Unknown | Mouser | 588-LVK20R100CER | 1.49 | 5.96
89 | R96, R97, R101, R102, R246, R247, R339, R340, R341, R342, R343, R344, R345, R346, R347, R348, R349, R350, R351, R352, R353, R354, R356, R357, R358, R359, R360, R361, R362, R363, R364, R365, R366, R367, R368, R369, R370, R371 | 38 | 1K1 0.063W 1% 0402 (1005 Metric) SMD | Yageo | RC0402FR-071K1L | Volume Production | Mouser | 603-RC0402FR-071K1L | 0.012 | 0.456
90 | R99 | 1 | 130R 0.1W 5% 0603 (1608 Metric) SMD | Panasonic | ERJ-3GEYJ131V | Volume Production | Mouser | 667-ERJ-3GEYJ131V | 0.1 | 0.1
91 | R126 | 1 |  | Panasonic | ERJ-3EKF2001V | Volume Production | Digi-Key | P2.00KHDKR-ND | 0.1 | 0.1
92 | R171A, R171B, R171C, R171D, R171E, R171F, R171G, R171H, R177A, R177B, R177C, R177D, R177E, R177F, R177G, R177H, R182, R188 | 18 | 61R9 0.063W 1% 0402 (1005 Metric) SMD | Yageo | RC0402FR-0761R9L | Volume Production | Mouser | 603-RC0402FR-0761R9L | 0.012 | 0.216
93 | R173A, R173B, R173C, R173D, R173E, R173F, R173G, R173H, R176A, R176B, R176C, R176D, R176E, R176F, R176G, R176H, R184, R187 | 18 | 165R 0.063W 1% 0402 (1005 Metric) SMD | Yageo | RC0402FR-07165RL | Volume Production | Digi-Key | YAG2999CT-ND | 0.016 | 0.288
94 | R174A, R174B, R174C, R174D, R174E, R174F, R174G, R174H, R175A, R175B, R175C, R175D, R175E, R175F, R175G, R175H, R185, R186 | 18 | 15R 0.063W 1% 0402 (1005 Metric) SMD | Yageo | RC0402FR-0715RL | Volume Production | Mouser | 603-RC0402FR-0715RL | 0.012 | 0.216
95 | R178A, R178B, R178C, R178D, R178E, R178F, R178G, R178H, R181A, R181B, R181C, R181D, R181E, R181F, R181G, R181H, R189, R190 | 18 | 348R 0.063W 1% 0402 (1005 Metric) SMD | Yageo | RC0402FR-07348RL | Volume Production | Mouser | 603-RC0402FR-07348RL | 0.014 | 0.252
96 | R193, R261, R262, R267, R268, R273, R274, R279, R280, R285 | 10 | 18R 0.063W 1% 0402 (1005 Metric) SMD | Panasonic | ERJ-2RKF18R0X | Volume Production | Newark | 64R5261 | 0.004 | 0.04
97 | R250, R252, R253, R254, R255, R256, R257, R258, R259 | 9 | 33R 0.063W 1% 0402 (1005 Metric) SMD | Bourns | CR0402-FX-33R0GLF | Volume Production | Mouser | 652-CR0402FX-33R0GLF | 0.006 | 0.06
98 | R251 | 1 | 25R5 0.063W 1% 0402 (1005 Metric) SMD | Yageo | RC0402FR-0725R5L | Volume Production | Mouser | 603-RC0402FR-0725R5L | 0.1 | 0.1
99 | R260 | 1 | 10R 0.1W 1% 0603 (1608 Metric) SMD | Panasonic | ERJ3EKF10R0V | Volume Production | Digi-Key | P10.0HDKR-ND | 0.1 | 0.1
100 | R288, R289, R291 | 3 | Chip Resistor, 22 Ohm, +/- 1%, 100 mW, -55 to 155 degC, 0603 (1608 Metric) | Vishay | CRCW060322R0FKEA | Volume Production
101 | R290, R292 | 2 | RES SMD 16.9k OHM 5% 1/10W 0603 | Panasonic | ERJ3EKF1692V | Volume Production | Mouser | 667-ERJ-3EKF1692V | 0.1 | 0.2
102 | S1, S2, S3 | 3 | Tactile Switches Tact 6.2 x 6.2, 5.1 mm H, 1.7N, J leads, Potting Friendly, IP67 | ITT C&K | KSC421J70SHLFSPF | Unknown | Mouser | 611-KSC421J70SHLFSPF | 0.56 | 1.68
103 | T1 | 1 | WE-RJ45 LAN Transformer, 10/100/1000 Base-T, THT, Port 1x1, Tab Up | Wurth Electronics | 7499111221A | Volume Production | Mouser | 710-7499111221A | 11.56 | 11.56
104 | TP1, TP2, TP4, TP5, TP7, TP8, TP10, TP12, TP14, TP16, TP18, TP20, TP22, TP23, TP25, TP27, TP29, TP31, TP33, TP35, TP36, TP40, TP41, TP42, TP76, TP77, TP78, TP79, TP80, TP81, TP82 | 31 | Circuit Board Hardware - PCB SMT Mini Test Terminal, Reel | Harwin | S2761-46R | Volume Production | Newark | 76Y5391
105 | TP3, TP6, TP9, TP11, TP13, TP15, TP17, TP19, TP21, TP24, TP26, TP28, TP32, TP34, TP37, TP38, TP39, TP83, TP84, TP85, TP86, TP87 | 22 | Circuit Board Hardware - PCB TEST POINT BLK .063 | Keystone Electronics | 5006 | Volume Production | Mouser | 534-5006 | 0.335 | 7.37
106 | TP72, TP73, TP74, TP75 | 4 | Headers & Wire Housings Unshrouded 1 POS T/H | TE Connectivity | 5-146280-1 | Volume Production | Mouser | 571-51462801 | 0.41 | 1.64
107 | U1, U2, U6 | 3 | Single Output High PSRR LDO, 500 mA, Fixed 2.5 V Output, 2.7 to 5.5 V Input, 6-pin SOT-223 (DCQ), -40 to 125 degC, Green (RoHS & no Sb/Br) | Texas Instruments | TPS79525DCQR | Volume Production | Mouser | 595-TPS79525DCQR | 3.09 | 9.27
108 | U3 | 1 | LDO Voltage Regulators 5A Low VIN LDO Regulator with 0.5Vref | Microchip | MIC69502WR-TR | Volume Production | Mouser | 998-MIC69502WRTR | 2.98 | 2.98
109 | U4 | 1 | LDO Voltage Regulators 0.5A Hi PSRR FT LDO 2.5V | Analog Devices | ADM7170ACPZ-2.5-R7 | Volume Production | Mouser | 584-ADM7170ACPZ2.5R7 | 2.75 | 2.75
110 | U5 | 1 | Single Output High PSRR LDO, 500 mA, Fixed 3 V Output, 2.7 to 5.5 V Input, 6-pin SOT-223 (DCQ), -40 to 125 degC, Green (RoHS & no Sb/Br) | Texas Instruments | TPS79530DCQR | Volume Production | Mouser | 595-TPS79530DCQR | 3.08 | 3.08
111 | U7 | 1 | Single Output LDO, 300 mA, Fixed 1.8 V Output, 2 to 5.5 V Input, with Low IQ, 5-pin SOT-23 (DBV), -40 to 125 degC, Green (RoHS & no Sb/Br) | Texas Instruments | TLV70218DBVT | Volume Production | Mouser | 595-TLV70218DBVT | 0.58 | 0.58
112 | U8 | 1 | Single Output High PSRR LDO, 1.5 A, Fixed 1.8 V Output, 2.7 to 5.5 V Input, 6-pin SOT-223 (DCQ), -40 to 125 degC, Green (RoHS & no Sb/Br) | Texas Instruments | TPS78618DCQ | Volume Production | Digi-Key | 296-34652-5-ND | 4.89 | 4.89
113 | U9 | 1 | Single Output High PSRR LDO, 250 mA, Fixed 2.5 V Output, 2.7 to 5.5 V Input, 6-pin SOT-223 (DCQ), -40 to 85 degC, Green (RoHS & no Sb/Br) | Texas Instruments | TPS79425DCQR | Volume Production | Mouser | 595-TPS79425DCQR | 2.08 | 2.08
114 | U10 | 1 | No Description Available | Maxim | MAX6820UT+T | Not Recommended for New Design | Mouser | 700-MAX6820UTT | 4.89 | 4.89
115 | U11, U12 | 2 | Single Output Fast RF LDO, 200 mA, Fixed 3.3 V Output, 2.7 to 5.5 V Input, 5-pin SOT-23 (DBV), -40 to 125 degC, Green (RoHS & no Sb/Br) | Texas Instruments | TPS79333DBVREP | Volume Production | Mouser | 595-TPS79333DBVREP | 2.81 | 5.62
116 | U13 | 1 | Single Output High PSRR LDO, 500 mA, Fixed 2.5 V Output, 2.7 to 5.5 V Input, 6-pin SOT-223 (DCQ), -40 to 125 degC, Green (RoHS & no Sb/Br) | Texas Instruments | TPS79525DCQR | Volume Production | Mouser | 595-TPS79525DCQR | 3.09 | 3.09
117 | U14, U18, U19, U23, U24, U29, U30 | 7 | Current & Power Monitors & Regulators Automotive, 36-V, Ultra-High Accuracy, Low-/High-Side, I2C Out Current/Power Monitor w/ Alert 10-VSSOP -40 to 125 | Texas Instruments | INA226AQDGSRQ1 | Volume Production | Mouser | 595-INA226AQDGSRQ1
118 | U15 | 1 | Clock Synthesizer / Jitter Cleaner Single PLL jitter attenuator with xtal: 12-outputs up to 1028 MHz; integer+fractional | Silicon Labs | SI5395A-A-GM | Unknown | Mouser | 634-SI5395A-A-GM | 31.67 | 31.67
119 | U16 | 1 | Interface - I/O Expanders 60BIT IO EXPANDER W/EEPROM | Cypress | CY8C9560A-24AXI | Volume Production | Mouser | 727-CY8C9560A-24AXI | 9.85 | 9.85
120 | U17 | 1 | DRS4 QFN76 DAQ Chip
121 | U20, U22, U33 | 3 | Board Mount Temperature Sensors Hi-Prec Lo-Pwr Dig Temp Sensor | Texas Instruments | TMP112AIDRLR | Volume Production | Mouser | 595-TMP112AIDRLR
122 | U21 | 1 | Analog to Digital Converters - ADC 14-Bit 40 MSPS 3V | Analog Devices | AD9245BCPZ-40 | Volume Production | Digi-Key | AD9245BCPZ-40-ND | 34.31 | 34.31
123 | U25A, U25B, U25C, U25D, U25E, U25F, U25G, U25H, U26 | 9 | RF Switch ICs DC-6 GHZ Hi Isolation Switch | Analog Devices | HMC849ALP4CE | Volume Production | Mouser | 584-HMC849ALP4CE | 7.75 | 69.75
124 | U27 | 1 | USB Interface IC USB to Serial UART Enhanced IC QFN-32 | FTDI | FT232RQ-REEL | Volume Production | Mouser | 895-FT232RQ
125 | U28 | 1 | LDO Voltage Regulators 1.8V 3-Lead SOT-23 300mA Ultra Low Iq LDO with Auto-Discharge | Microchip | MCP1812AT-018/TT | Unknown | Mouser | 579-MCP1812AT-018/TT | 0.39 | 0.39
126 | U31 | 1 | High-Side Measurement Current-Shunt Monitor with Comparator and Reference | Texas Instruments | INA200AIDR | Volume Production | Mouser | 595-INA200AIDR | 2.8 | 2.8
127 | U32 | 1 | Board Mount Hall Effect / Magnetic Sensors Ultra Lo-Pwr Hi Perf 3-Axis 1.9-3.6V | STMicroelectronics | LIS3MDLTR | Volume Production | Mouser | 511-LIS3MDLTR
128 | U34 | 1 | Board Mount Humidity Sensors | Bosch | BME280 | Unknown | Digi-Key | 828-1063-6-ND | 6.84 | 6.84
129 | U35 | 1 | Interface - I/O Expanders SDIO Port Expander | Texas Instruments | TXS02612RTWR | Volume Production | Mouser | 595-TXS02612RTWR | 1.45 | 1.45
130 | U36 | 1 | Clock Buffer LVCMOS 2:12 buffer (200MHz), 2:1 LVCMOS input max, output enable (QFN24) | Silicon Labs | SI53362-B-GM | Unknown | Mouser | 634-SI53362-B-GM | 1.53 | 1.53
131 | U37 | 1 | Digital to Analog Converters - DAC 16-bit octal I2C nanoDAC | Analog Devices | AD5675BCPZ-REEL7 | Volume Production | Mouser | 584-AD5675BCPZ-REEL7 | 18.92 | 18.92
132 | U38 | 1 | Ultralow Noise, High Accuracy Voltage Reference, 2.048 V Output, 3 to 15 V Supply, Industrial, 8-pin SOIC (R-8), Reel | Analog Devices | ADR4520BRZ-R7 | Volume Production | Mouser | 584-ADR4520BRZ-R7 | 8.2 | 8.2
133 | U39, U40 | 2 | Multiplexer Switch ICs 8CH I2C SWTCH W/REST | NXP Semiconductors | PCA9548ABS,118 | Volume Production | Mouser | 771-PCA9548ABS118 | 1.91 | 3.82
134 | U43 | 1 | IC OPAMP GP 1 CIRCUIT SOT23-5 | Texas Instruments | LM321LVIDBVR | Unknown | Mouser | 595-LM321LVIDBVR | 0.48 | 0.48
135 | U44, U45 | 2 | Supervisory Circuits 2.93V Monitor | Texas Instruments | TLC7733IPWR | Volume Production | Mouser | 595-TLC7733IPWR | 2.44 | 4.88
136 | U46, U47, U48 | 3 | 3.6V Data-Line Surge and 30kV ESD Protection Diode | Texas Instruments | ESDS312DBVR | Unknown | Digi-Key | 296-51112-1-ND | 0.63 | 1.89
137 | U49 | 1 |  | Maxim | MAX11645EUA+ | Volume Production | Mouser | 700-MAX11645EUA+ | 2.07 | 2.07
138 | XTAL1 | 1 | TCXO Oscillators 50MHz 5x3.2x1.5mm 0.2ppm max Crystal | Murata | XTCLH50M000CHJA3P0 | Unknown | Mouser | 81-XTCLH50M000CHJA3P | 14.72 | 14.72
139 | XTAL2 | 1 | TCXO Oscillators 25MHz 3.3Volt LVCMOS 0.280 ppm -40C 85C | Abracon | AST3TQ-T-25.000MHz-28 | Volume Production | Digikey | 535-12700-ND

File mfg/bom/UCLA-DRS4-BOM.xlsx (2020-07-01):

Line # | Designator | Quantity | Name | Description | Manufacturer 1 | Manufacturer Part Number 1 | Notes
 | C1, C2, C3, C4, C5, C6, C29, C30, C52, C53, C145, C146, C147, C148, C149 | 15 | Cap_Kemet_T521B226M025ATE100_22uF | Tantalum Capacitors - Polymer SMD 25V 22uF 1311 20% ESR=100mOhms | KEMET | T521B226M025ATE100
 | C7, C9, C10, C11, C12, C14, C15, C16, C17, C18, C19, C21, C23, C24, C25, C27, C28, C31, C32, C33, C35, C36, C38, C39, C40, C41, C43, C44, C45, C47, C49, C50, C51, C54, C56, C65, C76, C245 | 38 | Cap_Murata_ZRB18AR6YA475ME05L_4.7uF | CAP CER 4.7uF 35V X5R 0603 | Murata | ZRB18AR6YA475ME05L
 | C8, C13, C22, C26, C34, C37, C42, C46, C48, C57, C61, C62, C94, C95, C243, C252, C253, C255, C258, C262, C326 | 21 | Cap_Kemet_C0603C103J5RACTU_eec | CAP CER 10nF 50V X7R 0603 | KEMET | C0603C103J5RACTU
 | C20, C55, C58, C59, C60, C86, C87, C88, C89, C90, C91, C93, C102, C109, C110, C111, C112, C113, C115, C116, C117, C118, C119, C121, C122, C126, C128, C129, C130, C131, C132, C133, C134, C139, C140, C141, C142, C143, C151, C152, C153, C154, C155, C162, C163, C165, C166, C167, C168, C169, C170, C171, C172, C173, C174, C175, C178, C180, C186, C187, C188, C189, C190, C192A, C192B, C192C, C192D, C192E, C192F, C192G, C192H, C194A, C194B, C194C, C194D, C194E, C194F, C194G, C194H, C196A, C196B, C196C, C196D, C196E, C196F, C196G, C196H, C197A, C197B, C197C, C197D, C197E, C197F, C197G, C197H, C198A, C198B, C198C, C198D, C198E, C198F, C198G, C198H, C199A, C199B, C199C, C199D, C199E, C199F, C199G, C199H, C202A, C202B, C202C, C202D, C202E, C202F, C202G, C202H, C205A, C205B, C205C, C205D, C205E, C205F, C205G, C205H, C212A, C212B, C212C, C212D, C212E, C212F, C212G, C212H, C213, C215, C217, C218, C219, C220, C223, C226, C233, C238, C239, C240, C241, C246, C247, C248, C249, C250, C251, C254, C256, C257, C259, C261, C263, C264, C265, C266, C267, C268, C269, C275, C314, C315, C316, C317, C318, C319, C321, C323, C324, C327, C328, C329, C334, C335 | 181 | Cap_Taiyo_Yuden_TMK105B7104KV-FR_100nF | CAP CER 100nF 25V X7R 0402 | Taiyo Yuden | TMK105B7104KV-FR
 | C63, C64, C66, C70, C74, C75, C77, C81, C114, C127, C144, C150, C176, C185, C200A, C200B, C200C, C200D, C200E, C200F, C200G, C200H, C201A, C201B, C201C, C201D, C201E, C201F, C201G, C201H, C203A, C203B, C203C, C203D, C203E, C203F, C203G, C203H, C204A, C204B, C204C, C204D, C204E, C204F, C204G, C204H, C221, C222, C224, C225, C244, C274, C320, C322, C325, C341 | 56 | Cap_Murata_ GRM21BC71E106ME11L_10uF | CAP CER 10uF 25V X7R 0805 | Murata | GRM21BC71E106ME11L
 | C67, C68, C69, C71, C72, C73, C78, C79, C80, C82, C83, C84, C96, C97, C98, C99, C100, C101, C103, C104, C105, C106, C107, C108, C124, C260, C271, C272, C273, C330, C331, C332, C333, C337 | 34 | Cap_Murata_GCJ188R71E105KA01J_1uF | CAP CER 1uF 25V X7R 0603 | Murata | GCJ188R71E105KA01J
 | C85, C159, C160, C161, C164 | 5 | Cap_Murata_GJM1555C1H200GB01D_20pF | Multilayer Ceramic Capacitors MLCC - SMD/SMT 0402 20pF 50Volts C0G 2% | Murata | GJM1555C1H200GB01D
 | C92 | 1 | Cap_Murata_GCQ1555C1H120FB01D_12pF | MLCC - SMD/SMT 0402 50VDC 12pF 1% AEC-Q200 | Murata | GCQ1555C1H120FB01D
 | C120 | 1 | C0402C562K5RACTU | CAP CER 5600PF 50V X7R 0402 | KEMET | C0402C562K5RACTU
 | C123, C276, C277 | 3 | Cap_Murata_GRT21BR61E226ME13L_22uF | CAP CER 22uF 25V X5R 0805 | Murata | GRT21BR61E226ME13L
 | C125, C270 | 2 | CAP 4.7nF 10V 0603(1608) | CAP 4.7nF 10V ±10% 0603 (1608 Metric) Thickness 1mm SMD | KEMET | C0603C472K8RACTU
 | C135, C156 | 2 | Cap_Murata_GRM31CR61A107ME05L_100uF | CAP CER 100uF 25V X5R 0603 | Murata | GRM31CR61A107ME05L
 | C136, C137, C138, C157, C158 | 5 | Cap_Kemet_C0603C101J5RACTU_100pF | CAP CER 100pF 50V X7R 0603 | KEMET | C0603C101J5RAC7867
 | C177, C179, C181, C182, C183, C184, C191, C336 | 8 | Cap_Kemet_C0603C102J5RACAUTO_1nF | CAP CER 1nF 50V X7R 0603 | KEMET | C0603C102J5RACAUTO
 | C193A, C193B, C193C, C193D, C193E, C193F, C193G, C193H, C195A, C195B, C195C, C195D, C195E, C195F, C195G, C195H, C214, C216 | 18 | Cap_Wurth_Electronics_885012206075_470nF | CAP CER 470nF 25V X7R 0603 | Wurth Electronics | 885012206075
 | C206A, C206B, C206C, C206D, C206E, C206F, C206G, C206H, C207A, C207B, C207C, C207D, C207E, C207F, C207G, C207H, C208A, C208B, C208C, C208D, C208E, C208F, C208G, C208H, C209A, C209B, C209C, C209D, C209E, C209F, C209G, C209H, C210A, C210B, C210C, C210D, C210E, C210F, C210G, C210H, C211A, C211B, C211C, C211D, C211E, C211F, C211G, C211H, C227, C228, C229, C230, C231, C232 | 54 | Cap_TDK_C1608X5R1A106M080AC_220nF | CAP CER 220nF 50V X7R 0402 | TDK | C1005X7R1E224K050BE
 | C234, C235, C278, C281, C282, C285, C286, C289, C290, C293, C294, C297, C298, C301, C302, C305, C306, C309, C310, C313 | 20 | Cap_TDK_CGA2B2C0G2A151J050BE_150pF | CAP 150pF 50V C0G ±1% 0402 (1000 Metric) Thickness 1mm SMD | TDK | CGA2B2C0G2A151J050BE
 | C236, C237, C279, C280, C283, C284, C287, C288, C291, C292, C295, C296, C299, C300, C303, C304, C307, C308, C311, C312 | 20 | Cap_Murata_GCM1555C1H271FA16D_270pF | CAP 270pF 50V C0G ±1% 0402 | Murata | GCM1555C1H271FA16D
 | C242 | 1 | CAP 2.2uF 16V 0603(1608) | CAP 2.2uF 16V ±10% 0603 (1608 Metric) Thickness 1mm SMD | KEMET | C0603C225K4PACTU
 | C338, C339, C340, C342 | 4 | Cap_Kemet_C0603C104M5RACAUTO_100nF | CAP CER 100nF 50V X7R 0603 | KEMET | C0603C104M5RACAUTO
 | D1, D2, D3, D4 | 4 | ESD9B5.0ST5G | Transient Voltage Suppressor, Micro-Packaged Diode for ESD Protection, 2-Pin SOD-923, Pb-Free, Tape and Reel | ON Semiconductor | ESD9B5.0ST5G
 | D5, D6, D7, D13, D20, D31, D32 | 7 | BZT52C4V3-7-F | Zener Diodes 500mW 4.3V Zener AEC-Q101 Qualified | Diodes | BZT52C4V3-7-F
 | D8, D9, D10, D11, D12, D14, D15, D16, D17, D18, D21 | 11 | Diode_ON_Semiconductor_1N4148WT_300mA | Diodes - General Purpose, Power, Switching SINGLE JUNC. 75V 4.0NS COMP | Rectron | 1N4148WT
 | D19, D22 | 2 | Led_Lite-On_LTST-C193KGKT-5A_Green | Standard LEDs - SMD Green 470nm 28mcd 20mA | Vishay Lite-On | LTST-C193KGKT-5A
 | D23, D26, D27, D33, D34, D35, D36, D37, D38, D45, D46, D47, D48 | 13 | LTST-C193KRKT-5A | Standard LEDs - SMD Red 470nm 28mcd 20mA | Vishay Lite-On | LTST-C193KRKT-5A
 | D24, D25, D49, D54, D55, D56, D57, D58 | 8 | PRTR5V0U4D,125 | ESD Suppressors / TVS Diodes 5.5V QUAD R-R ESD ULTRA LOW CAP | Nexperia | PRTR5V0U4D,125
 | D28 | 1 | ESD_LittleFuse_SP3304NUTG_3V3 | ESD Suppressors / TVS Diodes 4CH 20A 3.3V 3.5pF Lightning Protection | Littelfuse | SP3304NUTG
 | D29, D30, D41 | 3 | Diode_SP3003-04ATG_LVDS_ESD | ESD Suppressors / TVS Diodes 4 Ch 8kV 0.65pF SPA | Littelfuse | SP3003-04ATG
 | D39A, D39B, D39C, D39D, D39E, D39F, D39G, D39H, D40 | 9 | BAV99S | Silicon Switching Diode, SOT363, Reel, Green | Infineon | BAV99S
 | D42 | 1 | ESD_Bourns_ CDNBS08-SRDA05-4_5V | ESD Suppressors / TVS Diodes SO-8 5V 500W Low Capacitance | Bourns | CDNBS08-SRDA05-4
 | D43, D44, D59, D60, D61, D62, D63, D64, D65, D66, D67, D68, D69, D70, D71, D72, D73, D74, D75, D76, D77, D78, D79, D80, D81 | 25 | Led_Lite-On_LTST-C193TBKT-5A_Blue | Standard LEDs - SMD Blue 470nm 28mcd 20mA | Vishay Lite-On | LTST-C193TBKT-5A
 | D50, D51, D52, D53, D82, D83 | 6 | 5V_ESD_Littlefuse_SP1212-01ETG_30kV | ESD Suppressors / TVS Diodes 5V 12A 30KV UNI-DIR | Littelfuse | SP1212-01ETG
 | F1, F2, F3, F5 | 4 | 3A hold, 5.2 A trip | Resettable Fuses - PPTC 3A 24V PPTC 2920 SMD | Bel | 0ZCF0300BF2C
 | F4 | 1 | 2A hold, 3.5 A trip | 2A hold, 3.5A trip | Bel | 0ZCG0200AF2B
 | FB1, FB2, FB3, FB4, FB5, FB29 | 6 | FBMH4532HM681-T | Chip Bead Inductor for Power Lines, 680 Ohm, 4 A, -40 to 125 degC, 2-Pin 4.5 x 3.2 x 3.5 mm SMD, RoHS, Taping | Taiyo | FBMH4532HM681-T
 | FB6, FB7 | 2 | 30 Ohm | Feb SMD 30 OHM 25% 3/4W 0402 | Murata | BLM15AX300SZ1D
 | FB8, FB9, FB10A, FB10B, FB10C, FB10D, FB10E, FB10F, FB10G, FB10H, FB11A, FB11B, FB11C, FB11D, FB11E, FB11F, FB11G, FB11H, FB12A, FB12B, FB12C, FB12D, FB12E, FB12F, FB12G, FB12H, FB13, FB14, FB15, FB17, FB18, FB19, FB20, FB21, FB22, FB24, FB25, FB26, FB27, FB28 | 40 | 742792731 | FB SMD 100 OHM 25% 1.2A 0402 | Wurth Electronics | 742792731
 | FB16, FB23 | 2 | FB_MURATA_BLM15AX102SZ1D_1k | FB SMD 1000 OHM 25% 3/4W 0402 | Murata | BLM15AX102SZ1D
 | J1 | 1 | RJ45_TE_Connectivity_5406299-1 | Modular Connectors / Ethernet Connectors 1 PORT CAT 5 | TE Connectivity | 6116202-1
 | J2 | 1 | Header_TE_Connectivity_1586041-8_8POS | Headers & Wire Housings RA HDR W/O PEGS 8P | TE Connectivity | 1586041-8
 | J3, J19 | 2 | Header_TE_Connectivity_87224-3_3POS | Headers & Wire Housings UNSHRD VERT SNGL 3 | AMP - TE CONNECTIVITY | 87224-3
 | J4 | 1 | DIMM_TE_Connectivity_1473005-4_200POS | DIMM Connectors DDR2 SODIMM 200P STANDARD HOUSING | AMP - TE CONNECTIVITY | 1473005-4
 | J5 | 1 | Header_Molex_87832-1420_14POS | Headers & Wire Housings 14P SMD PB FREE SHRD | Molex | 0878321420
 | J6, J7, J8, J10, J11 | 5 | Header_TE_Connectivity_826936-2_2POS_5A | Headers & Wire Housings 2P SINGLE ROW 5A | TE Connectivity | 826936-2
 | J9A, J9B, J9C, J9D, J9E, J9F, J9G, J9H | 8 | CONREVSMA003.062 | RP-SMA Female Edge Mount Connector for 0.062" Thick Board | Linx | CONREVSMA003.062
 | J12 | 1 | uUSB CONN | USB Connectors WR-COM USB Micro SMT Type B Horiztl | Wurth Electronics | 629105150521
 | J13 | 1 | Conn_Molex_47219-2001_eec | CONN MICRO SD CARD HINGED TYPE | Molex | 0472192001
 | J14 | 1 | Header_Molex_87758-4416_44POS | Headers & Wire Housings VERT HEADER 44P Lead Free | Molex | 87758-4416
 | J15, J18 | 2 | Header_Harwin_M50-3530242_2POS | Headers & Wire Housings 2 WAY SIL VERT PC TAIL P/HDR | Harwin | M50-3530242
 | J16 | 1 | Header_Harwin_ M22-2510605 _6POS | Headers & Wire Housings 6 WAY SIL VERT PC TAIL P/HDR | Harwin | M22-2510605
 | J17 | 1 | Header_Harwin_M22-2510705_7POS | Headers & Wire Housings 6 WAY SIL VERT PC TAIL P/HDR | Harwin | M22-2510705
 | L1, L9 | 2 | 0603 250 mA | IND 10µH Shielded Multilayer Inductor 250mA 1.365 Ohm Max 0603 (1608 Metric) | TDK | MLZ1608M100WT000
 | L2A, L2B, L2C, L2D, L2E, L2F, L2G, L2H, L3A, L3B, L3C, L3D, L3E, L3F, L3G, L3H, L4, L5 | 18 | Ind_TDK_ MLG1005SR22JT000_220nH | Fixed Inductors .22 UH 5% | TDK | MLG1005SR22JT000
 | L6, L8, L10, L12, L13, L15, L16, L18, L19, L21, L22, L24, L25, L27, L28, L30, L31, L33, L34, L36 | 20 | 470nH 0402 5% | IND 470nH Shielded Multilayer Inductor 50mA 420 mOhm Max 0402 (1005 Metric) | TDK | MLF1005GR47JT000
 | L7, L11, L14, L17, L20, L23, L26, L29, L32, L35 | 10 | 510nH 0402 2% | IND 510nH Shielded Multilayer Inductor 70mA 10.2 Ohm Max 0402 (1005 Metric) | TDK | MHQ1005PR51GT000
 | OP1A, OP1B, OP1C, OP1D, OP1E, OP1F, OP1G, OP1H, OP2 | 9 | THS4509 | Differential Amplifier 1 Circuit Differential 16-QFN (3x3) | Texas Instruments | THS4509RGTT
 | OP3 | 1 | AD8608ARZ-REEL | IC OPAMP GP 4 CIRCUIT 14SOIC | Analog Devices | AD8608ARZ-REEL
 | Q1, Q2, Q3, Q4 | 4 | Mos_ROHM_RSJ250P10FRATL_25A | MOSFET Pch -100V Vds -25A 0.05Rds(on) 60Qg | Rohm | RSJ250P10FRATL
 | Q5, Q6, Q11 | 3 | Mos_ROHM_EM6K6T2R_N_300mA | MOSFET Small Signal Dual N-CH 20V .3A .15W | Rohm | EM6K6T2R
 | Q7, Q8, Q9, Q15, Q16, Q17, Q18, Q19, Q20, Q22, Q23, Q24, Q25 | 13 | BJT_PNP_Toshiba_TMBT3906 | Bipolar Transistors - BJT Transistor for Low Freq. Amplification | Toshiba | TMBT3906,LM
 | Q10, Q12, Q13, Q14 | 4 | Mos_Alpha&Omega_AO3401A_4A | P-Channel 30V 4A (Ta) 1.4W (Ta) Surface Mount SOT-23-3L | Alpha & Omega Semiconductor | AO3401A
 | Q21, Q26, Q27, Q28, Q29, Q30, Q31, Q32, Q33, Q34, Q35 | 11 | BJT_ROHM_US6X8TR_1A_NPN | Bipolar Transistors - BJT NPN+NPN 30VCEO 1A SOT-363T | Rohm | US6X8TR
 | Q36, Q37 | 2 | BJT_ROHM_EMT52T2R_100mA_PNP | Bipolar Transistors - BJT Bipolar Transistor SOT-563 SC-107C EMT6 | Rohm | EMT52T2R
 | Q38 | 1 | MOS_Fairchild_FDS6699S_PCHN | MOSFET 30V N-Ch PowerTrench SyncFET | ON Semiconductor / Fairchild | FDS6699S
 | R1, R3, R5, R14, R89, R118, R155, R156 | 8 | SRes_KOA_PSG4NTEB1L00F_1mOhm | Current Sense Resistors - SMD 1mOhm 8W 1% 50ppm AEC-Q200 Power Shunt | KOA Speer | PSG4NTEB1L00F
 | R2, R4, R6, R15, R23, R24, R26, R27, R34 | 9 | 47K 5% 0603(1608) | 47K 0.1W 5% 0603 (1608 Metric) SMD | Vishay | CRCW060347K0JNEA
 | R7 | 1 | 27K 5% 0603(1608) | 27K 0.1W 5% 0603 (1608 Metric) SMD | Vishay Dale | CRCW060327K0JNEA
 | R8, R9 | 2 | 24K 5% 0603(1608) | 24K 0.1W 5% 0603 (1608 Metric) SMD | Vishay Dale | CRCW060324K0JNEA
 | R10, R33, R51, R53, R63, R65, R95, R107, R129, R141, R167, R168, R204, R205, R215, R216, R217, R222, R300, R301, R302, R303, R304, R305, R306, R307, R316, R317, R318, R319, R320, R321, R322, R323, R328, R329, R330, R331, R332, R333, R334 | 41 | 10K 5% 0603(1608) | 10K 0.1W 5% 0603 (1608 Metric) SMD | Vishay Dale | CRCW060310K0JNEA
 | R11 | 1 | Res_Yageo_RC0402FR-132K49L_2.48kOhm | Thick Film Resistors - SMD 2.49K ohm 1% 50V General Purpose | Yageo | RC0402FR-132K49L
 | R12 | 1 | 22K 5% 0603(1608) | 22K 0.1W 5% 0603 (1608 Metric) SMD | Vishay Dale | CRCW060322K0JNEA
 | R13, R16, R19, R20, R37, R38, R39, R40 | 8 | 20K 1% 0603(1608) | 20K 0.1W 1% 0603 (1608 Metric) SMD | Vishay | CRCW060320K0FKEA
 | R17, R18 | 2 | 15K 5% 0603(1608) | 15K 0.1W 5% 0603 (1608 Metric) SMD | Panasonic | ERJ-3GEYJ153V
 | R21 | 1 | 33K 5% 0603(1608) | 33K 0.1W 5% 0603 (1608 Metric) SMD | Vishay Dale | CRCW060333K0JNEA
 | R22, R30, R35, R54, R55, R61, R62, R100, R108, R130, R147, R169, R170, R202, R203, R218, R219, R220, R223, R292, R293, R294, R295, R296, R297, R298, R299, R308, R309, R310, R311, R312, R313, R314, R315, R324, R325, R326, R327, R335, R336, R337 | 42 | 680R 5% 0603(1608) | 680R 0.1W 5% 0603 (1608 Metric) SMD | Panasonic | ERJ-3GEYJ681V
 | R25, R29, R200 | 3 | 1K 5% 0603(1608) | 1K 0.1W 5% 0603 (1608 Metric) SMD | Bourns | CR0603-JW-102ELF
 | R28, R32, R64, R66, R67, R68, R70, R71, R72, R73, R74, R75, R76, R77, R78, R79, R80, R81, R82, R83, R84, R85, R86, R87, R88, R90, R92, R94, R103, R105, R144, R145, R146, R148, R149, R150, R151, R152, R153, R154, R157, R158, R159, R160, R161, R162, R165, R166, R198, R199, R201, R206, R207, R208, R212, R213, R214, R224, R225, R226, R227, R228, R229, R230, R231, R232, R233, R234, R235, R236, R237, R238, R247, R248 | 74 | Res_Vishay_CRCW04020000Z0EDC_0_Ohm | 0R 0.062W 1% 0402 (1005 Metric) SMD | Vishay | CRCW04020000Z0EDC
 | R31, R48, R49, R91, R104, R119, R139, R163, R164, R209, R210, R211, R221 | 13 | 100K 5% 0603(1608) | 100K 0.1W 5% 0603 (1608 Metric) SMD | Panasonic | ERJ-3GEYJ104V
 | R36 | 1 | Res_ROHM_SFR01MZPF20R0_20_Ohm | 20R 62.5mW 1% 0402 (1005 Metric) SMD | Rohm | SFR01MZPF20R0
 | R41, R43, R44, R56, R57, R93, R98, R109, R110, R111, R112, R113, R114, R115, R116, R117 | 16 | 100R 5% 0402(1005) | 100R 0.063W 5% 0402 (1005 Metric) SMD | Panasonic | ERJ-2GEJ101X
 | R42, R50, R52, R140, R143, R179A, R179B, R179C, R179D, R179E, R179F, R179G, R179H, R180A, R180B, R180C, R180D, R180E, R180F, R180G, R180H, R191, R192 | 23 | 22R 1% 0402(1005) | 22R 0.063W 1% 0402 (1005 Metric) SMD | Panasonic | ERJ-2RKF22R0X
 | R45, R106, R142, R172A, R172B, R172C, R172D, R172E, R172F, R172G, R172H, R183 | 12 | 49R9 1% 0402(1005) | 49R9 0.063W 1% 0402 (1005 Metric) SMD | Panasonic | ERJ2RKF49R9X
 | R46, R47, R196, R197, R354, R371 | 6 | RES_DNP_0603 | 0603 Do not place resistor |  |  | DNP
 | R58 | 1 | 8K 1% 0603 | 8K 0.1W 1% 0603 (1608 Metric) SMD | Yageo | RT0603BRE078KL
 | R59 | 1 | Res_Vishay_CRCW0603523RFKEA_523Ohm | RES SMD 523 OHM 1% 1/10W 0603 | Vishay | CRCW0603523RFKEA
 | R60 | 1 | Res_Bourns_CR0603-FX-4420ELF_442Ohm | RES SMD 442 OHM 1% 1/10W 0603 | Bourns | CR0603-FX-4420ELF
 | R69, R194, R195, R262, R263, R264, R265, R268, R269, R270, R271, R274, R275, R276, R277, R280, R281, R282, R283, R285, R286 | 21 | 300R 1% 0402(1005) | 300R 0.063W 1% 0402 (1005 Metric) SMD | Vishay | CRCW0402300RFKED
 | R96, R97, R101, R102, R120, R121, R122, R123, R124, R125, R126, R127, R128, R131, R132, R133, R134, R135, R136, R137, R138, R239, R240, R241, R242, R243, R244, R245, R246, R338, R339, R340, R341, R342, R343, R344, R345, R346, R347, R348, R349, R350, R351, R352, R353, R355, R356, R357, R358, R359, R360, R361, R362, R363, R364, R365, R366, R367, R368, R369, R370 | 61 | 1K1 1% 0402(1005) | 1K1 0.063W 1% 0402 (1005 Metric) SMD | Panasonic | ERJ-2RKF1101X
 | R99 | 1 | 130R 5% 0603(1608) | 130R 0.1W 5% 0603 (1608 Metric) SMD | Panasonic | ERJ-3GEYJ131V
 | R171A, R171B, R171C, R171D, R171E, R171F, R171G, R171H, R177A, R177B, R177C, R177D, R177E, R177F, R177G, R177H, R182, R188 | 18 | 61R9 1% 0402(1005) | 61R9 0.063W 1% 0402 (1005 Metric) SMD | Panasonic | ERJ-2RKF61R9X
 | R173A, R173B, R173C, R173D, R173E, R173F, R173G, R173H, R176A, R176B, R176C, R176D, R176E, R176F, R176G, R176H, R184, R187 | 18 | 165R 1% 0402(1005) | 165R 0.063W 1% 0402 (1005 Metric) SMD | Yageo | RC0402FR-07165RL
 | R174A, R174B, R174C, R174D, R174E, R174F, R174G, R174H, R175A, R175B, R175C, R175D, R175E, R175F, R175G, R175H, R185, R186 | 18 | 15R 1% 0402(1005) | 15R 0.063W 1% 0402 (1005 Metric) SMD | Panasonic | ERJ-2RKF15R0X
 | R178A, R178B, R178C, R178D, R178E, R178F, R178G, R178H, R181A, R181B, R181C, R181D, R181E, R181F, R181G, R181H, R189, R190 | 18 | 348R 1% 0402(1005) | 348R 0.063W 1% 0402 (1005 Metric) SMD | Vishay | CRCW0402348RFKED
 | R193, R260, R261, R266, R267, R272, R273, R278, R279, R284 | 10 | 18R 1% 0402(1005) | 18R 0.063W 1% 0402 (1005 Metric) SMD | Vishay | CRCW040218R0FKED
 | R249, R251, R252, R253, R254, R255, R256, R257, R258 | 9 | 33R 1% 0402(1005) | 33R 0.063W 1% 0402 (1005 Metric) SMD | Panasonic | ERJ-2RKF33R0X
 | R250 | 1 | 25R5 1% 0402(1005) | 25R5 0.063W 1% 0402 (1005 Metric) SMD | Panasonic | ERJ-2RKF25R5X
 | R259 | 1 | 10R 1% 0603(1608) | 10R 0.1W 1% 0603 (1608 Metric) SMD | Bourns | CR0603-FX-10R0ELF
 | R287, R288, R290 | 3 | Resistor 22R +/-1% 0603 100 mW | Chip Resistor, 22 Ohm, +/- 1%, 100 mW, -55 to 155 degC, 0603 (1608 Metric) | Yageo | RC0603FR-0722RL
 | R289, R291 | 2 | Res_Panasonic_ERJ-3EKF1692V_16.9kOhm | RES SMD 16.9k OHM 5% 1/4W 0603 | Panasonic | ERJ3EKF1692V
 | R372, R373, R374, R375, R376, R377, R378, R379 | 8 | Res_Vishay_CRCW06030000Z0EAHP_0_Ohm | 0R 0.25W 1% 0603 (1608 Metric) SMD | Vishay Dale | CRCW06030000Z0EAHP
 | S1, S2, S3 | 3 | SPDT_C&K_KSC421J70SHLFSPF_50mA | Tactile Switches Tact 6.2 x 6.2, 5.1 mm H, 1.7N, J leads, Potting Friendly, IP67 | ITT C&K | KSC421J70SHLFSPF
 | T1 | 1 | 7499111221A | WE-RJ45 LAN Transformer, 10/100/1000 Base-T, THT, Port 1x1, Tab Up | Wurth Electronics | 7499111221A
 | TP1, TP2, TP4, TP5, TP7, TP8, TP10, TP12, TP14, TP16, TP18, TP20, TP22, TP23, TP25, TP27, TP29, TP31, TP33, TP35, TP36, TP76, TP77, TP78, TP79, TP80, TP81, TP82 | 28 | TP_Harwin_S2761_46R | Circuit Board Hardware - PCB SMT Mini Test Terminal, Reel | Harwin | S2761-46R
 | TP3, TP6, TP9, TP11, TP13, TP15, TP17, TP19, TP21, TP24, TP26, TP28, TP30, TP32, TP34, TP37, TP38, TP56, TP57, TP58, TP59, TP60, TP61, TP62, TP65, TP66, TP67, TP68, TP69, TP70, TP71, TP83, TP84, TP85, TP86, TP87 | 36 | TP_Keystone_Electronics_5006 | Circuit Board Hardware - PCB TEST POINT BLK .063 | Keystone Electronics | 5006
 | TP39, TP40, TP41, TP42, TP43, TP44, TP45, TP46, TP47, TP48, TP49, TP50, TP51, TP52, TP53, TP54, TP55, TP63, TP64, TP72, TP73, TP74, TP75 | 23 | TP_TE_Connectivity_5-146280-1_1POS | Headers & Wire Housings Unshrouded 1 POS T/H | AMP - TE CONNECTIVITY | 5-146280-1
 | U1, U2, U6 | 3 | TPS79525DCQR | Single Output High PSRR LDO, 500 mA, Fixed 2.5 V Output, 2.7 to 5.5 V Input, 6-pin SOT-223 (DCQ), -40 to 125 degC, Green (RoHS & no Sb/Br) | Texas Instruments | TPS79525DCQR
 | U3 | 1 | LDO_Microchip_MIC69502WR-TR_ADJ | LDO Voltage Regulators 5A Low VIN LDO Regulator with 0.5Vref | Microchip | MIC69502WR-TR
 | U4 | 1 | LDO_Analog_Devices_ADM7170ACPZ-2.5-R7_2.5V | LDO Voltage Regulators 0.5A Hi PSRR FT LDO 2.5V | Analog Devices | ADM7170ACPZ-2.5-R7
 | U5 | 1 | TPS79530DCQR | Single Output High PSRR LDO, 500 mA, Fixed 3 V Output, 2.7 to 5.5 V Input, 6-pin SOT-223 (DCQ), -40 to 125 degC, Green (RoHS & no Sb/Br) | Texas Instruments | TPS79530DCQR
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

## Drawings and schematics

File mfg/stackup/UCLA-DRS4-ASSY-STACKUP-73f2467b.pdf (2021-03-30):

A

B

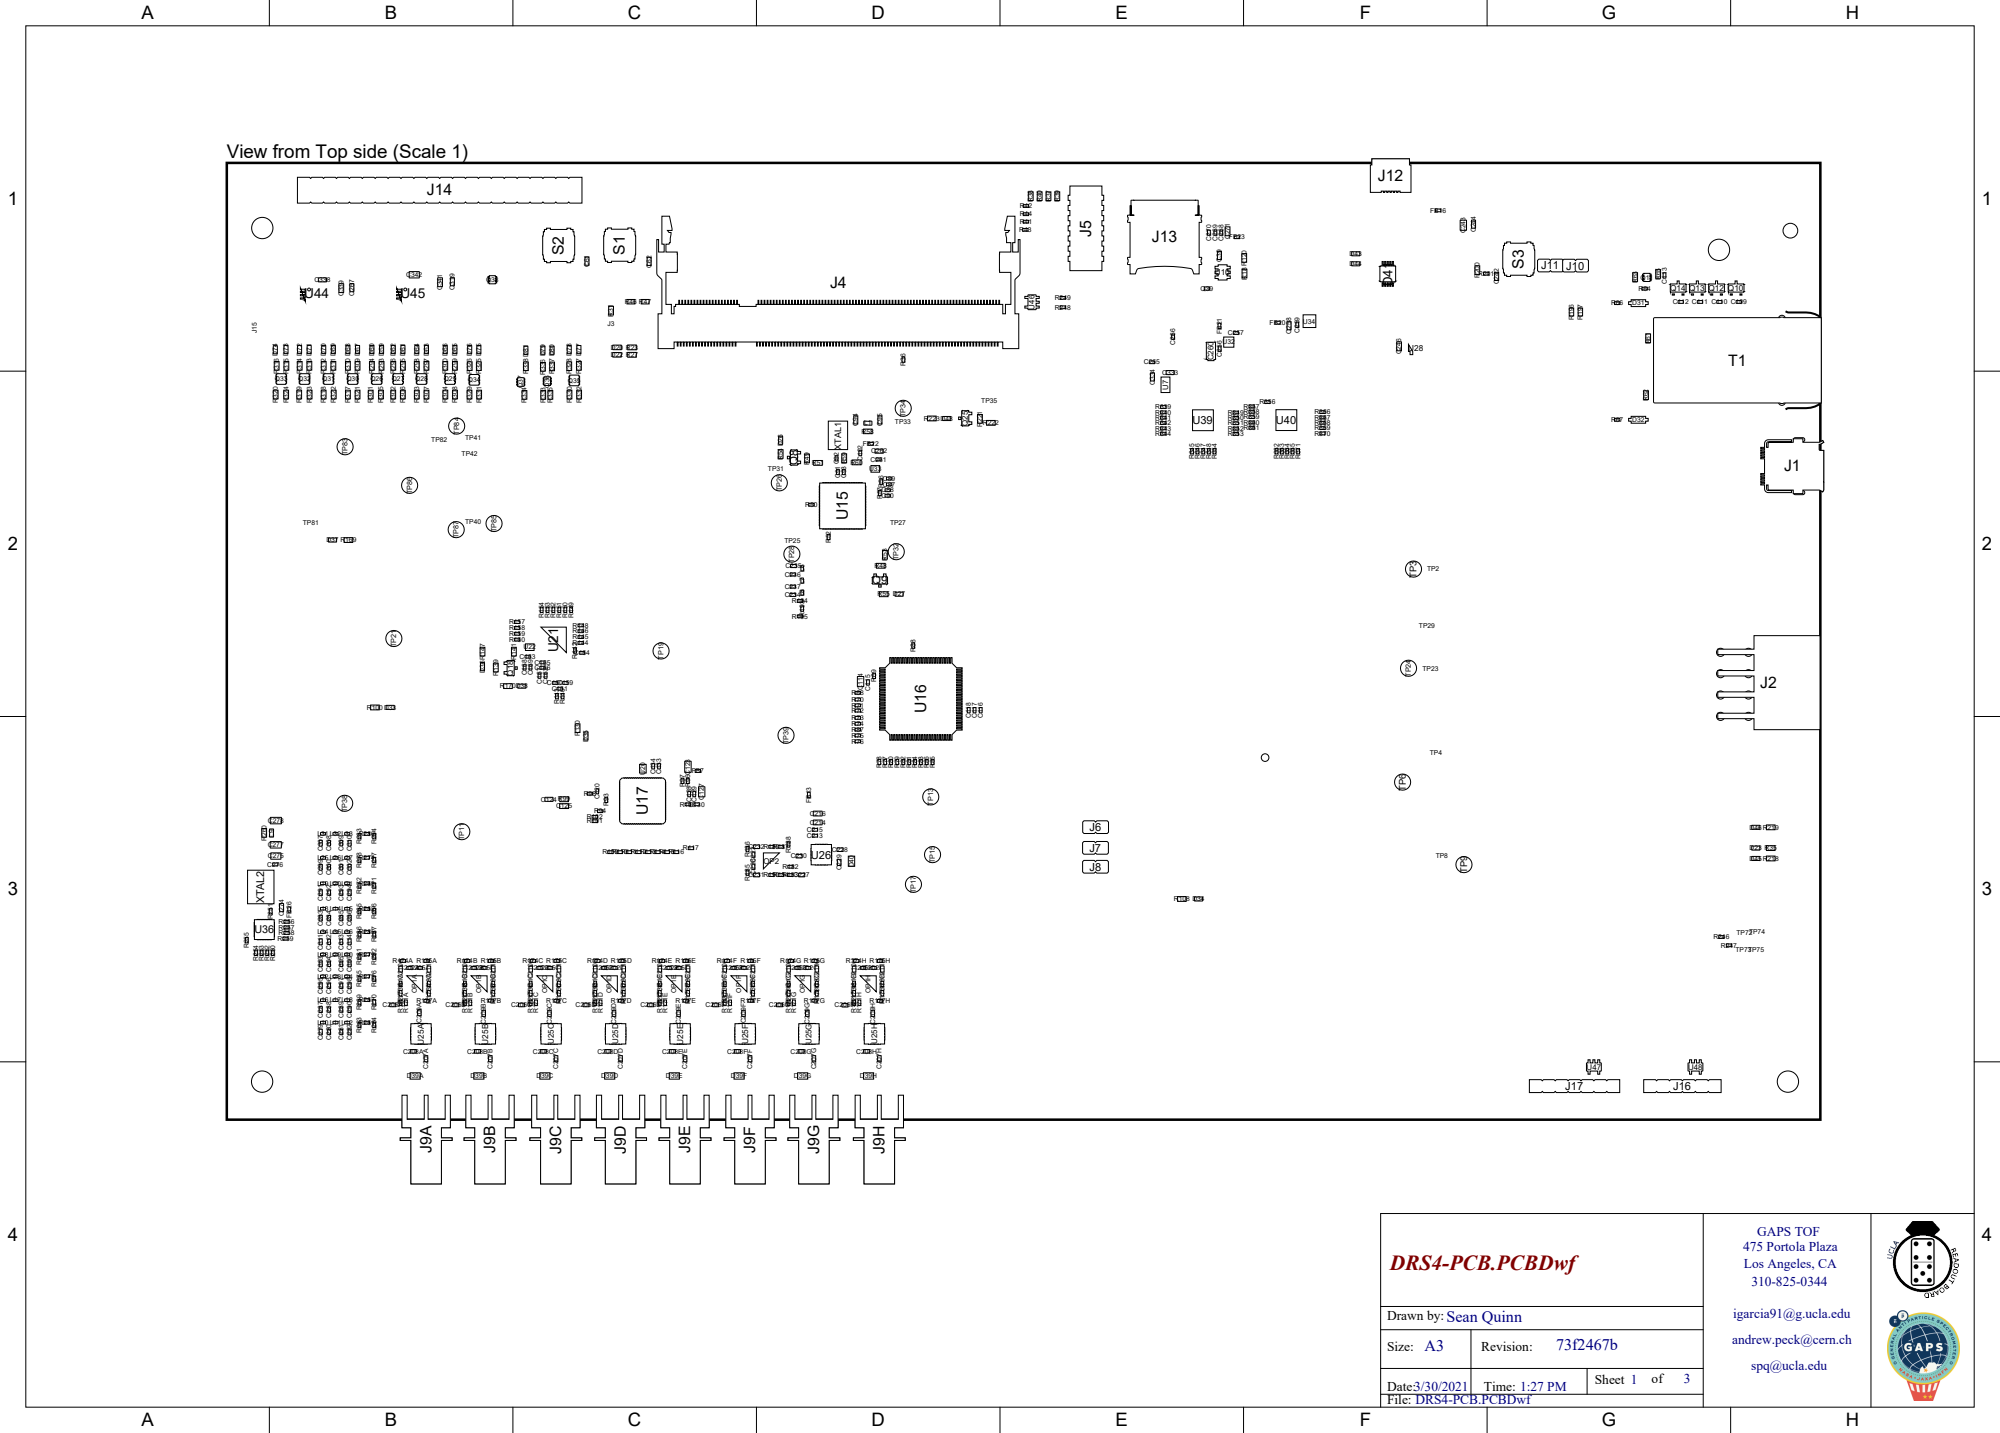
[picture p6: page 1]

View from Top side (Scale 1)

igarcia91@g.ucla.edu
andrew.peck@cern.ch
spq@ucla.edu

1 | 1

# C322 C³¹⁸

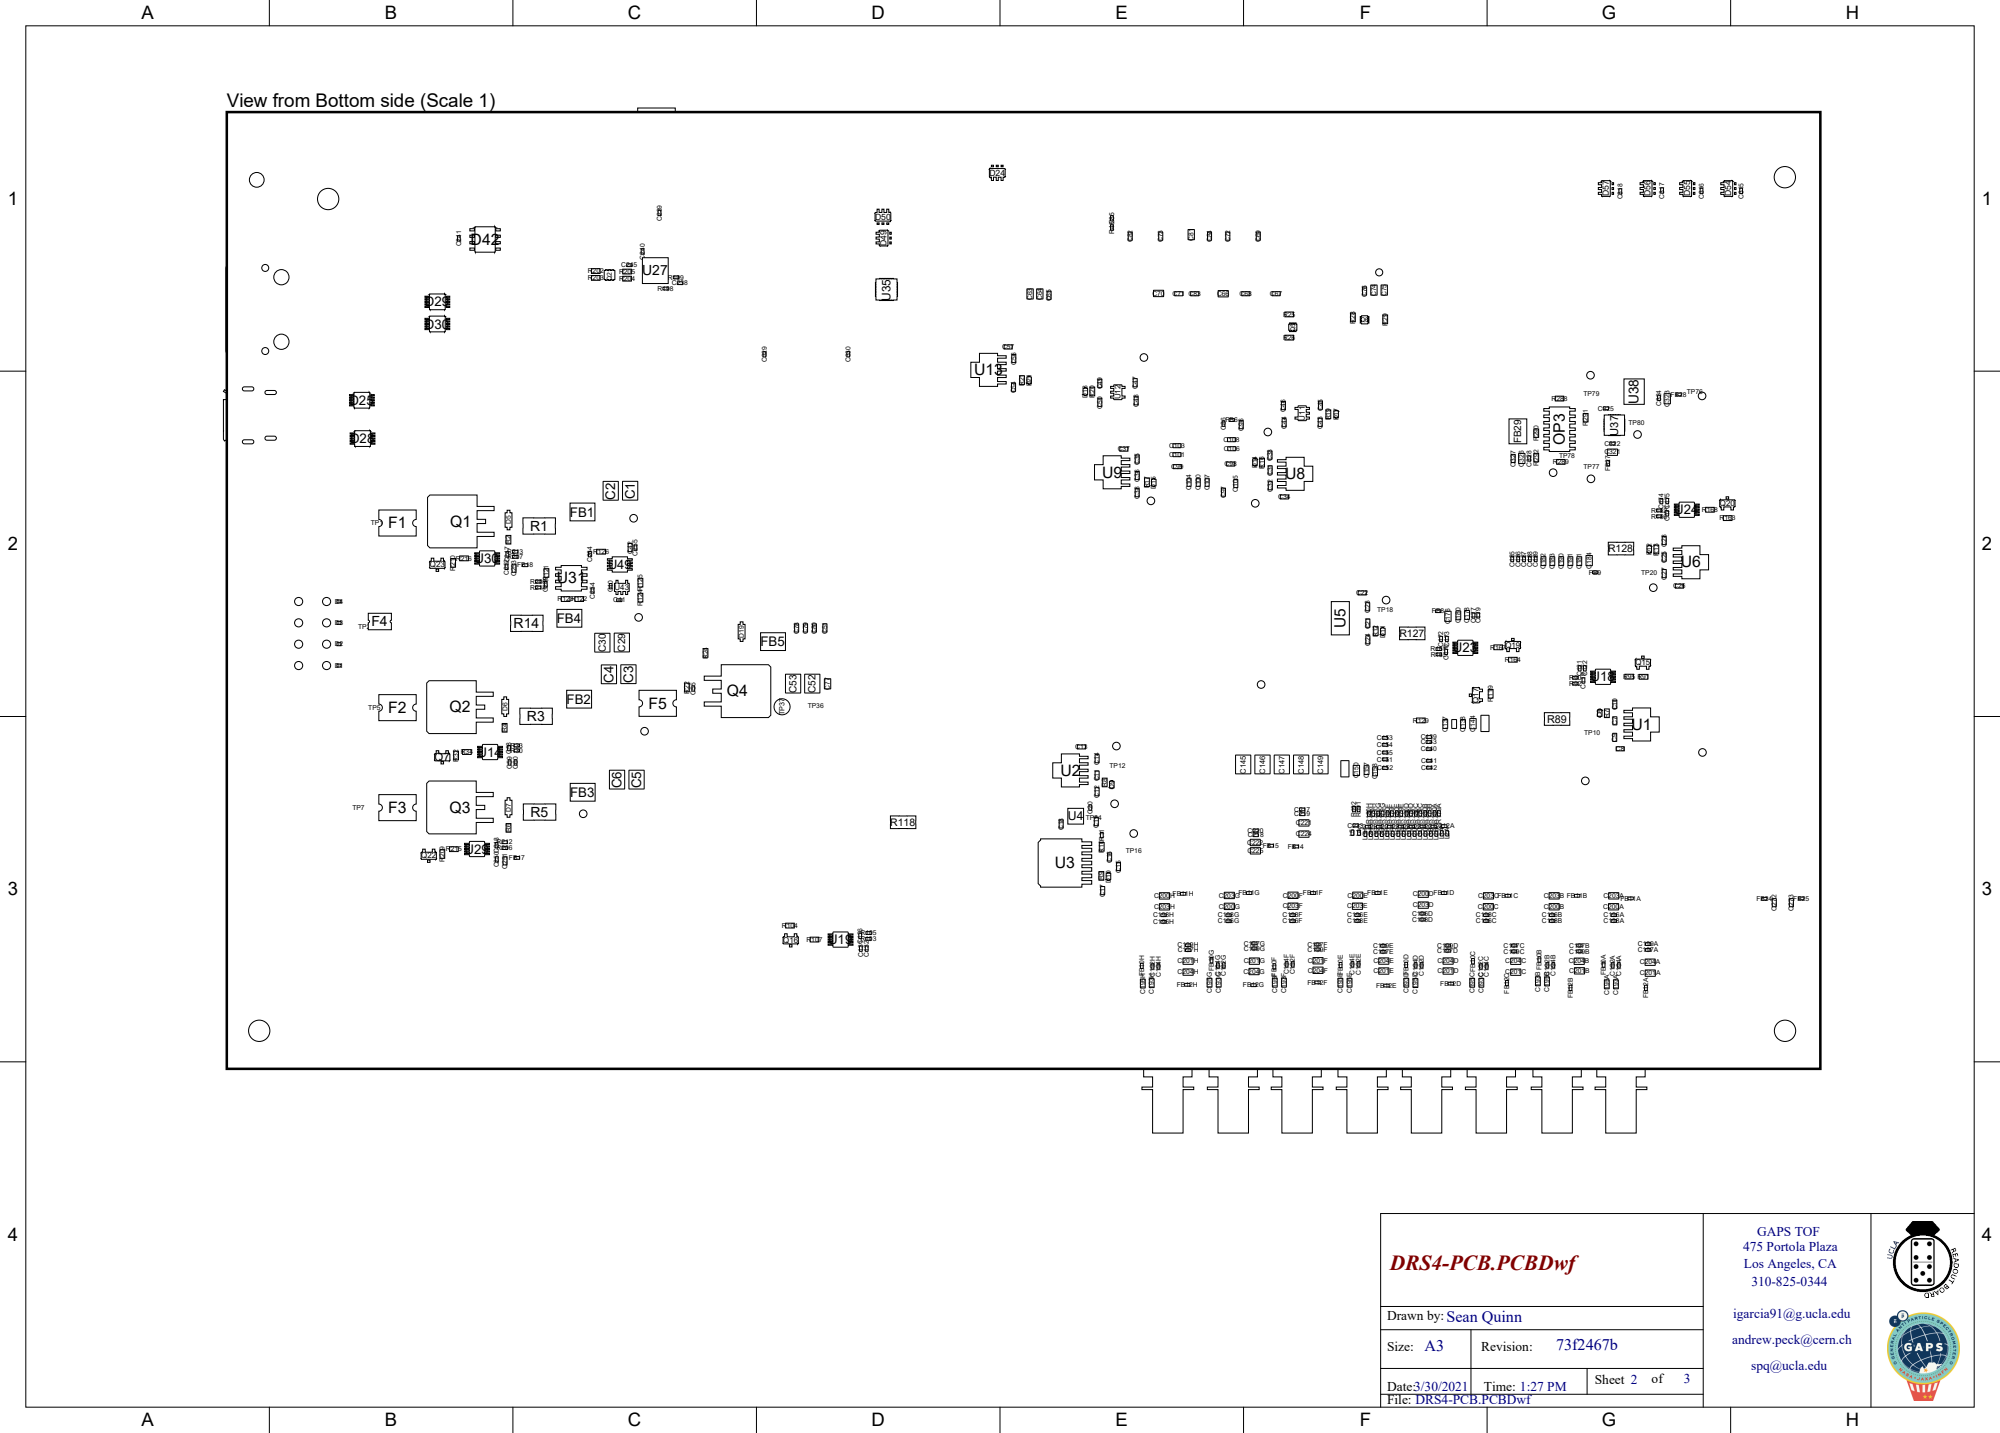
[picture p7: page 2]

View from Bottom side (Scale 1)

1 | 1
2 | 2
3 | 3
4 | 4

# DRS4-PCB.PCBDwf

# GAPS TOF 475 Portola Plaza Los Angeles, CA

310-825-0344

Material | Layer | Thickness Dielectric Material Type | Gerber
| Top Overlay | | | Legend | GTO
Surface Material Top Solder | 0.80mil | SM-005 | Solder Mask GTS
CF-007 | Top Layer | 1.60mil | 1/2 oz | Signal | GTL
Prepreg | | 4.48mil | FR408(HR) | Dielectric
CF-008 | Ground Layer 2 1.20mil | 1/2 oz | Signal | G1
Core | | 4.00mil | FR408(HR) | Dielectric
CF-008 | Signal Layer 3 | 1.20mil | 1/2 oz | Signal | G2
Prepreg | | 4.36mil | FR408(HR) | Dielectric
CF-008 | Signal Layer 4 | 1.20mil | 1/2 oz | Signal | G3
Core | | 4.00mil | FR408(HR) | Dielectric
CF-008 | Ground Layer 5 1.20mil | 1/2 oz | Signal | G4
Prepreg | | 4.36mil | FR408(HR) | Dielectric
CF-008 | Power Layer 6 | 1.20mil | 1/2 oz | Signal | G5
Core | | 4.00mil | FR408(HR) | Dielectric
CF-008 | Ground Layer 7 1.20mil | 1/2 oz | Signal | G6
Prepreg | | 4.36mil | FR408(HR) | Dielectric
CF-008 | Ground Layer 8 1.20mil | 1/2 oz | Signal | G7
Core | | 4.00mil | FR408(HR) | Dielectric
CF-008 | Power Layer 9 | 1.20mil | 1/2 oz | Signal | G8
Prepreg | | 4.36mil | FR408(HR) | Dielectric
CF-008 | Power Layer 10 1.20mil | 1/2 oz | Signal | G9
Core | | 4.00mil | FR408(HR) | Dielectric
CF-008 | Ground Layer 11 1.20mil | 1/2 oz | Signal | G10
Prepreg | | 4.48mil | FR408(HR) | Dielectric
CF-007 | Bottom Layer | 1.60mil | 1/2 oz | Signal | GBL
Surface Material Bottom Solder | 0.80mil | SM-005 | Solder Mask GBS
| Bottom Overlay | | | Legend | GBO

# Total thickness: 63.20mil

# Layer Stack Legend

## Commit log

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2020-04-30 updated PCB impedance with latest stackup in ./Output Files/Stackup.
    [UCLA_ReadOut_Gerber_4-29-19.GBL, UCLA_ReadOut_Gerber_4-29-19.GBO, UCLA_ReadOut_Gerber_4-29-19.GBP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]
2020-05-15 V2.1 review changes - Cleaned up top and bottom overlay (remove overlaps with copper) - Fix U17 footprint issue - Reduce layer 10 impedance discontuinities - Reduce crosstalk for HMC849 control lines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
    [-1V_DIST.SchDoc, 1V8_SUPPLY.SchDoc, 2V5_DRS4_SUPPLY.SchDoc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]
2020-05-15 Updated BU4230FVE with correct footprint
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2020-05-25 Stackup work * Added correct materials for stackup * Added data from Polar stackup to Altium project * Saved materials library to project folder (xml)
2020-05-26 Stackup improvements and impedance control * Resolve numerous schematic compilation errors * Introduced net classes for imedpance control nets * Explicitly state in schematics Z control nets * Rules 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
    [ANA_FE.SchDoc, ANA_FE_CLK_SYNTH.SchDoc, CLK_SYNTH.SchDoc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]
2020-05-27 Finish impedance control rework * Re-routed any tracks causing violations * Fixed all remaining schematic compilation problems * Added .rul file with stackup specific impedance control rules * Re-sav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
    [ANA_FE.SchDoc, ANA_FE_CLK_SYNTH.SchDoc, CLK_SYNTH.SchDoc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]
2020-05-28 Reorganized project. * Removed any versioning in folder names, etc.
    [-1V_DIST.SchDoc, 1V8_SUPPLY.SchDoc, 2049261103.stp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]
2020-06-24 BOM consolidation * Replace C128 with 0805 package (removes 1 line) * Change R15 and R18 to 20k, R16 and R17 to 15k.
    [CLK_PWR.SchDoc, MARS_PORB.SchDoc, UCLA-DRS4-2.1.PrjPCB]
2020-06-24 Housekeeping * Added missing parameters to several library parts * New active BOM
    [ANA_FE.SchDoc, ANA_FE_CLK_SYNTH.SchDoc, CLK_SYNTH.SchDoc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]
2020-06-26 Replace I2C isolators with TI part. Avoids supply chain issues.
2020-06-27 I2C iso simplification * Removed isolation circuits for TLTB, TPCB * Added 3D model for I2C header pins Rationale: TLTB_GND, TPCB_GND, and TRB_GND are electrically connected. It's simply not possible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
    [-1V_DIST.SchDoc, 1V8_SUPPLY.SchDoc, 2V5_DRS4_SUPPLY.SchDoc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]
2020-06-29 DAC sheet rework * Replaced LTC6269 with AD8608 * Removed SHDN * Replace Molex micro USB with Wurth Resolves several supply chain issues, and connectivity issues following re-annotation (pin swaps)
    [-1V_DIST.SchDoc, 1V8_SUPPLY.SchDoc, 2V5_DRS4_SUPPLY.SchDoc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]
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2020-07-01 Corrections from 6-29-20 meeting * Add voltage follower for unused DAC buffer op-amp * Remove isolated ground planes for I2C header conn Add fab and assembly docs used for V2.3 build package
    [ANA_FE.SchDoc, ANA_FE_CLK_SYNTH.SchDoc, DAC.SchDoc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]
2020-07-16 Fix ground cutout on layer 7 (previous I2C iso.).
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2020-08-31 Fix issues pointed out by Pactron CAM Check
    * Change DRS4_A1 via mask expansion from manual to rule (plugged to non-plugged)
    * Fix mask expansion for some traces (unmasked to masked)
    * Change J1 to round holes from slotted (unsure why default was slot)
    * Change J5 to round holes from slotted
    [TCA_CLK_DIST.SchDoc, UCLA-DRS4-2.1.PrjPCB]
2020-09-29 Replace 1.8V regulator in schematics and PCB.
    Closes #6
    [MARS_FTDI.SchDoc, UCLA-DRS4-2.1.PrjPCB]
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2020-10-13 Replace SMA connectors with new TE part. DRC passes.
    Closes #7.
    [ANA_FE.SchDoc]
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2020-10-17 Use Altium variants for DNI parts.
    * Remove annotation box around TI TLC7733 PWREN jumpers
    * Add jumpers above to DNI variant
    [MARS_PORB.SchDoc, UCLA-DRS4-2.1.PrjPCB]
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2020-10-22 Replace NFET schematic symbol
    [MarsCarrier_PWR.SchDoc]
2020-10-22 Replace nfet (Q11) with new symbol
    [ENET.SchDoc]
2020-10-22 Replace Q11 footprint with updated library part
2020-10-22 Change PORB nfet to EM6K part for readability and BOM consolidation.
    [MARS_PORB.SchDoc]
2020-10-22 Update PCB PORB nfet component (Q38) library part. Completes work to fix #11 and #13.
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2020-10-30 Add RC to TXS0261 VCCB0 pin to conform to power up spec
    [MARS_MIO.SchDoc]
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2020-10-30 Add delay back to SD level shifter schematics.
    [MARS_MIO.SchDoc]
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2020-11-01 Schematics: Tie VCCB1 to 3V3. Make D1 data/CLK NC. Conforms to Enclustra EB1 design.
    [MARS_MIO.SchDoc]
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2020-11-02 SCH: Replace SP1212-01ETG with ESDS312DBVR before Mars ZX2 I2C pins.
    [MARS_MIO.SchDoc]
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2020-11-02 SCH: Remove SP1212-01ETG from one of external I2C headers.
    [I2C_HEADER.SchDoc]
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2020-11-02 SCH: Add ESD to both external I2C header
    [I2C_HEADER.SchDoc]
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2020-11-02 SCH: Swap ESD pins for layout convenience
    [I2C_HEADER.SchDoc]
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2020-11-02 Save recent I2C ESD work to project. Closes #30.
    [UCLA-DRS4-2.1.PrjPCB]
2020-11-05 PCB: Fix stub on I2C ESD for Mars
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2020-11-05 SCH: Remove SD card test points and resistors.
    [MARS_MIO.SchDoc]
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2020-11-05 SCH: Remove incorrect ESD diodes from high speed SD CLK and CMD lines
    [MARS_MIO.SchDoc]
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2020-11-05 SCH: Add copy of PRTR5V0U4D,125 for SD CLK and SD CMD ESD protection
    [MARS_MIO.SchDoc]
2020-11-05 SCH: swap SD CLK and SD CMD for easier layout
    [MARS_MIO.SchDoc]
2020-11-05 SCH: Add uSD traces to S50 net class, impose length match rule for nets
    [MARS_MIO.SchDoc]
2020-11-06 SCH: Add S50 net class and uSD rules to SD traces from Mars carrier.
    [MarsCarrier.SchDoc]
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2020-11-13 Add new 2.54mm header library parts to project
    [UCLA-DRS4-2.1.PrjPCB]
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2020-11-13 SCH: Replace 44POS GPIO header with new 2.54 mm part.
    [MARS_GPIO_MISC.SchDoc]
2020-11-13 PCB: Replace/reroute 44pos gpio header with new 2.54mm part
2020-11-15 SCH: Replace power board I2C header with 2.54 mm part
    [I2C_HEADER.SchDoc]
2020-11-15 PCB: Replace power board I2C header with 2.54 mm part.
2020-11-16 SCH: Replace local trigger I2C header with 2.54 mm part
    [I2C_HEADER.SchDoc]
2020-11-16 PCB: Replace local trigger I2C header with 2.54 mm. Completes work on replacing all headers with 2.54 mm parts. Closes #20, #19.
2020-11-17 SCH: Remove ROHM power IC, jumper for 3V3_ZYNQ and VCC_TI_PORB, jumper for ROHM and TI circuit.
    [MARS_PORB.SchDoc]
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2020-11-17 PRJ: Remove old header parts from Altium project.
    [UCLA-DRS4-2.1.PrjPCB]
2020-11-17 SCH: Remove DNP resistors for I2C mux resetbar pins. Add text showing hardware selected address.
    [I2C_MULTIPLEX.SchDoc]
2020-11-17 PCB: Remove DNP resistors for I2C mux resetbar pins. Add text showing hardware address on silk. Closes #14.
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2020-11-19 SCH: Replace n-fet with new part with higher V_GS. Put over voltage resistor in series with Zener diode.
    [-1V_DIST.SchDoc]
2020-11-19 PCB: Replace n-fet with new part (negative analog rail). Move overvoltage resistor to be in series with Zener diode. Closes #12.
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2020-11-20 SCH: Remove bad characters from Misc GPIO harness type string
    [MARS_GPIO_MISC.SchDoc]
2020-11-20 SCH: Fix bad character in Misc IO string
    [MarsCarrier.SchDoc]
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2020-11-21 SCH: ENET.SchDoc Add length matching and D100 impedance rule for ethernet traces.
    [ENET.SchDoc]
2020-11-21 SCH: CLK_SYNTH Remove local trigger connectivity, add impedance control rules for differential pairs (main clock)
    [CLK_SYNTH.SchDoc]
2020-11-21 SCH: ToF Remove local trigger harness. Add ESD protection for RJ45 connector for main trigger data/clock
    [ToF.SchDoc]
2020-11-21 SCH: MARS_GPIO_MISC Remove GPIO nets now in use for trigger data. Remove ESD diode no longer needed for those GPIO header pins
    [MARS_GPIO_MISC.SchDoc]
2020-11-21 SCH: MarsCarrier Add main trigger data lines. Add rule for impedance control and length matching.
    [MarsCarrier.SchDoc]
2020-11-21 SCH: MARS_GPIO_MISC Fix compiler error (old nets still connected)
    [MARS_GPIO_MISC.SchDoc]
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2020-11-21 SCH: Adjust pair rules for some clock lines
    [MarsCarrier.SchDoc]
2020-11-21 SCH: Fix blanket containing blank header
    [MARS_GPIO_MISC.SchDoc]
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2020-11-21 SCH: Update length matching tolerance for MTRIG traces
    [ToF.SchDoc]
2020-11-22 SCH: Final revisions to schematics for addition of production trigger scheme.
    [CLK_SYNTH.SchDoc, MarsCarrier.SchDoc, ToF.SchDoc]
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2020-11-22 PRJ: Major updates to trigger routing, adding ESD protection, removing local trigger clock.
    [UCLA-DRS4-2.1.PrjPCB]
2020-11-22 SCH: Add suggestive box around SDIO on MarsCarrier
    [MarsCarrier.SchDoc]
2020-11-22 SCH: Remove bulky header test point from signal path
    [DRS4_ADC.SchDoc]
2020-11-22 SCH: DAC sheet, lock all signal test point designators
    [DAC.SchDoc]
2020-11-22 SCH: DAC Add some SMD test points for op-amp outputs
    [DAC.SchDoc]
2020-11-22 SCH: DRS4 Major rework of all test points. Simpler design using inline vias. Static labeling scheme on top overlay.
    [DRS4.SchDoc]
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2020-11-24 SCH: Lock designators for DRS4 supply test points
    [2V5_DRS4_SUPPLY.SchDoc]
2020-11-24 PCB: Rework DRS4 test points, closes #38, #17, #9. Lock test point designators and sync with silk screen, closes #26. Schematic improvements, fixes #22.
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2020-12-11 Remove res parts, wrong package *sigh*
    [UCLA-DRS4-2.1.PrjPCB]
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2020-12-11 Remove res files again. Just uses Altium database part anyway
    [UCLA-DRS4-2.1.PrjPCB]
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2021-03-10 Fix multiple harness warning for 3V3 and -1V current sense.
    [ToF.SchDoc]
2021-03-10 Fix 3V3 Zynq current sensor harness type warning
    [ToF.SchDoc]
2021-03-10 Fix humidity sensor harness type warning
    [ToF.SchDoc]
2021-03-10 Fix b-field sense harness warning
    [ToF.SchDoc]
2021-03-10 Fix DRS4 current sense harness type warning
    [ToF.SchDoc]
2021-03-10 * Fix DRS4 current/temp sense harness warning * Fix DRS4 refclk0 harness warning * Fix DRS4 harness warning * Fix GPIO harness warning
    [DSR4_MODULE.SchDoc, ToF.SchDoc]
2021-03-10 Add power electrical type to power connector pins, fixes some driving source warnings
    [ToF.SchDoc]
2021-03-10 Add power pins to various parts connected to 4V. Fixes no driving source warning.
    [4V_DIST.SchDoc, ToF.SchDoc]
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2021-03-11 PCBLIB: Fix Harting 3D part. Was type A, now type B
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2021-03-12 PCB: fix ext trig conn top overlay info
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2021-03-12 PCB * Adjust pgood trace width to avoid clearance violation * Nudge ETH_A pair away from hole to avoid clearance violation * Nudge VCTL5 away from via (clearance)
2021-03-12 PCB * Nudge VOUT- from DAC away from VOUT+ (clearance) * Nudge via near GPIO line (clearance) * Fix ADC power pin traces (clearance)
2021-03-12 PCB * Nudge RF SW EN7 away from ground via (clearance) * Reduce width of VCC trace and via diameter for Q5 (clearance) * Nudge IO_B35_L3_P at Mars DIMM (clearance)
2021-03-12 PCB * Nudge IO_MIO41_B13_L16_W9 (clearance) * Repour neutral polys * Fix ground planes under new connector
2021-03-12 PCB: Fix S50 violation for SDIO lines
2021-03-12 PCB: fix S50 width for sdio lines (top layer)
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2021-03-15 * Page ordering improvements * Update title block rev num. * Update sheet ordering and page numbers
    [-1V_DIST.SchDoc, 1V8_SUPPLY.SchDoc, 2V5_DRS4_SUPPLY.SchDoc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]
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2021-03-15 SCH: Add formula to PORB. Correct td (off by 1 ms).
    [MARS_PORB.SchDoc]
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2021-03-15 SCH: Replace SRCLK termination cap with 20pF part.
    [DRS4.SchDoc]
2021-03-15 PCB: Fix term cap for SRCLK. Change to 20 pF part. Closes #43.
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2021-03-16 PCB: Repour polys, fix Harting conn 3V3 connection
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2021-03-16 SCH: Change CLK VDD 3V3 source to 4V to achieve actual regulation
    [CLK_PWR.SchDoc]
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2021-03-17 SCH: Add info pages back into sub pages.. compiler error otherwise
    [ToF.SchDoc]
2021-03-18 PCB: Add power sequencing for SD translator. Correct fix for #23.
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2021-03-19 PCB: Replace 3V3_ZYNQ shunt with 39mohm
2021-03-19 Fix sch shunt res annotations
    [3V3_DIST_ZYNQ.SchDoc, 4V_DIST.SchDoc]
2021-03-19 SCH: Replace 3V3 shunt with 39 mOhm
    [3_3V_DIST.SchDoc]
2021-03-19 PCB: Replace 3V3 shunt with 30 mOhm
2021-03-19 SCH: Replace shunt for -1V with 39 mOhm
    [-1V_DIST.SchDoc]
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2021-03-19 SCH: Rework -1V sense * Remove INA226 * Place and connect INA200 for shunt res sense * Place and connect inv op amp for vbus sense * Place and connect Max11645 ADC for current and voltage readout * C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
    [Sensors.SchDoc]
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2021-03-19 SCH: Fix port name typo
    [-1V_DIST.SchDoc]
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2021-03-19 SCH: Fix port name typos in Sensors.SchDoc
    [Sensors.SchDoc]
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2021-03-23 SCH: Replace DRS4_AVDD shunt with 100 mOhm
    [DRS4.SchDoc]
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2021-03-23 SCH: Replace ADC_AVDD shunt with 100 mOhm
    [DRS4_ADC.SchDoc]
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2021-03-23 PCB: Fix SMA designators on top overlay (off the board)
2021-03-23 LIB: Fix Max11645 symbol and footprint linkage
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2021-03-23 PCB: Finish routing new circuits * -1V5 Current sense * -1V5 Voltage sense * Max1165 ADC * TI inverting amp * New 100 mOhm shunts * Top overlay documentation/improvements
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2021-03-30 SCH: Replace 1 uF ceramic with electrolytic for b-field sensor
    [Sensors.SchDoc]
2021-03-30 SCH: Change VDDIO supply for B-field sense * Remove 1V8 supply net * Connect 3V3 to VDDIO
    [Sensors.SchDoc]
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2021-03-30 SCH: B-field electrolytic * Replace Al with tantalum cap
    [Sensors.SchDoc]
2021-03-30 PCB: B-field sensor * Replace 1uF with electrolytic * Change VDDIO supply to 3V3
2021-03-30 PCB: Fix -1V sense nets.
2021-03-30 PCB: Fix ground layer under external trigger traces
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2021-03-30 SCH: Remove fet and diode for -1V_DIST. Revisit this later with workable solution.
    [-1V_DIST.SchDoc]
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2021-03-30 SCH: Replace 1V8 regulator with different package with better stock
    [1V8_SUPPLY.SchDoc]
2021-03-30 PCB: Replace 1V8 reg with different package with more availability
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2021-03-31 LIB: Fix power rating for chip res in description
2021-03-31 SCH: Update res with correct power rating
    [DAC.SchDoc]
2021-03-31 SCH: Sync to updated 100uF part with corrected parameters
    [DRS4.SchDoc]
2021-04-05 SCH: Remove AC termination for ADC_CLK. This trace is already series terminated at the source. The receiver does *not* need termination.
    [DRS4_ADC.SchDoc]
2021-04-05 SCH: fix ground symbol orientation
    [DRS4_ADC.SchDoc]
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2021-04-12 SCH: Remove OUT0 net, add NC to OUT0 port on synth chip
    [CLK_SYNTH.SchDoc]
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2021-04-12 SCH: Change synth output assignments For layout considerations * OUT1=ADC Clock * OUT2_P and OUT2_N are DRS REF CLK
    [CLK_SYNTH.SchDoc]
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2021-04-12 SCH WIP: Add 10uF TANT to REFT/REFB bypass Tidy up cap grouping. Work towards #53
    [DRS4_ADC.SchDoc]
2021-04-12 SCH: Replace one 100nF bypass on ADC VREF with 10uF TANT Work towards #54
    [DRS4_ADC.SchDoc]
2021-04-12 SCH: fix error in bypass circuit for REFT/REFB
    [DRS4_ADC.SchDoc]
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2021-04-12 PCB: Move I2C lines that were directly under ADC input pair to a different layer to avoid crosstalk
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2021-08-12 SCH: Update tcal lp filter sheet with new amplitude after switching clock to 2V5 supply
    [TCA_LP_FILTER.SchDoc]
2021-08-12 SCH: Update 9th channel sine wave amplitude. Fix typo. Improve description of lp filter circuit.
    [ANA_FE_CLK_SYNTH.SchDoc]
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2021-08-13 PCB: Fix TP38 silk label. Closes #59
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2021-08-13 PCB: *Actually* fix TP38 issue (wandering silk label). Closes #59. Correctly place silk designators for R1, R2, R5, R6. Closes #58.
